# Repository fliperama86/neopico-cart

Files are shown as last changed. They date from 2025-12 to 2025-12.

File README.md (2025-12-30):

# neopico-cart

An open-source Neo Geo MVS/AES flash cartridge using SDRAM instead of expensive parallel SRAM, targeting ~$100 BOM vs ~$1500+ for existing solutions.

## Project Goals

- Support largest games (~96-128 MB total ROM)
- Fast load times (~4 seconds for largest games)
- Cost-effective design using SDRAM with bank interleaving (MiSTer-inspired)
- Open-source hardware and software

## Architecture

```
┌───────────────────────────────────────────────────────────┐
│                      Flash Cart PCB                       │
│                                                           │
│  ┌──────────┐      ┌─────────────┐      ┌─────────────┐  │
│  │ SD Card  │─SPI─▶│  RP2350B    │      │   128MB     │  │
│  │ (.ngfc)  │      │             │      │   SDRAM     │  │
│  └──────────┘      │ • SD/FAT32  │      └──────┬──────┘  │
│                    │ • Menu UI   │             │         │
│                    │ • Config    │         16-bit        │
│                    └──────┬──────┘             │         │
│                           │                    │         │
│                       PIO/QSPI                 │         │
│                      (20-30 MB/s)              │         │
│                           │                    │         │
│                           ▼                    ▼         │
│              ┌────────────────────────────────────────┐  │
│              │          FPGA (ECP5 or Gowin)          │  │
│              │  • SDRAM controller (120MHz)           │  │
│              │  • 4-bank interleaving                 │  │
│              │  • Neo Geo bus interface               │  │
│              │  • Menu video generation               │  │
│              └───────────────────┬────────────────────┘  │
│                                  │                       │
│                           Level Shifters                 │
│                                  │                       │
└──────────────────────────────────┼───────────────────────┘
                                   │ 5V Bus
                                   ▼
                         ┌───────────────────┐
                         │   Neo Geo MVS/AES │
                         │   Cartridge Slot  │
                         └───────────────────┘
```

### Why Two Chips?

**RP2350 (~$1.50)** handles "software" tasks that are easy in C but painful in HDL:
- SD card FAT32 filesystem parsing
- Menu system and user input
- Configuration and save management
- Uses PIO for high-speed FPGA data transfer (20-30 MB/s)

**FPGA** handles timing-critical tasks requiring nanosecond precision:
- SDRAM controller with 4-bank interleaving
- Neo Geo bus interface (<250ns response for C-ROM)
- Real-time data serving during gameplay

Microcontrollers cannot serve real-time bus data due to timing constraints. Only FPGA + fast memory can meet these requirements. MiSTer proves SDRAM works with proper data reorganization and bank interleaving.

### Boot Sequence

1. RP2350 boots, initializes FPGA (bitstream from flash)
2. RP2350 reads SD card, displays menu via FPGA video
3. User selects game
4. RP2350 streams .ngfc file to FPGA via PIO (~4 sec for largest games)
5. FPGA writes to SDRAM as data arrives
6. FPGA switches to "play" mode, serves all bus requests
7. RP2350 monitors for menu button combo

## Bill of Materials Estimate

| Component | Part | Est. Cost |
|---|---|---|
| FPGA | Gowin GW2A-18 or Lattice ECP5-25 | $20 |
| SDRAM | AS4C64M16D3 (128MB) | $10 |
| MCU | RP2350B | $2 |
| Flash | W25Q128 (16MB for menu/loader) | $2 |
| Level Shifters | TXB0108 or similar (×4) | $6 |
| SD Card Slot | micro-SD | $1 |
| Voltage Regulators | 3.3V, 1.2V | $2 |
| PCB | 4-layer, Neo Geo form factor | $15 |
| Passives & Connectors | | $10 |
| **Total** | | **~$70-80** |

With 30% margin for revisions: **~$100**

## Current Status

### Phase 1: Research & Tooling ✅ Complete

- [x] Analyze existing solutions (BackBit, MiSTer, NeoSD)
- [x] Document timing requirements
- [x] Extract MiSTer transformation algorithms
- [x] Create ROM converter tool
- [x] Define NGFC file format
- [x] Cost analysis

### Phase 2: FPGA Development (Next)

- [ ] Set up FPGA toolchain (Gowin or Lattice)
- [ ] Implement SDRAM controller with bank interleaving
- [ ] Benchmark SDRAM latency/bandwidth
- [ ] Implement Neo Geo bus sniffer (for timing analysis)

### Phase 3: Hardware Prototyping

- [ ] Design breakout board for FPGA dev kit → Neo Geo
- [ ] Measure real C-ROM timing on actual hardware
- [ ] Validate timing margins

### Phase 4+: Full Implementation, Testing, Release

## Tools

### NGFC Converter

The `ngfc/` directory contains a Python tool for converting standard Neo Geo ROM sets to the NGFC format, optimized for SDRAM burst access.

```bash
# Convert a MAME ROM set
./ngfc/ngfc_converter.py convert mslug.zip mslug.ngfc

# Verify an NGFC file
./ngfc/ngfc_converter.py verify mslug.ngfc
```

See [ngfc/README.md](ngfc/README.md) for full documentation.

## Documentation

- [Feasibility Study](docs/neogeo-flashcart-research.md) - Comprehensive technical analysis
- [NGFC Converter](ngfc/README.md) - ROM conversion tool documentation

## References

- [NeoGeo Development Wiki](https://wiki.neogeodev.org/)
- [MiSTer NeoGeo Core](https://github.com/MiSTer-devel/NeoGeo_MiSTer)
- [BackBit Platinum MVS](https://store.backbit.io/product/backbit-platinum-mvs/)

## License

See [LICENSE](LICENSE) for details.

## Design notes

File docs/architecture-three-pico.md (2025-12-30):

# NeoPico-Cart Architecture: Triple RP2350 Design

## Overview

This document describes the "Triple Pico" architecture for the NeoPico-Cart — a Neo Geo MVS/AES flash cartridge using three RP2350 microcontrollers instead of FPGAs.

**Design Philosophy:**
- PSRAM data buses connect **directly** to Neo Geo (not through Picos)
- Picos handle **address translation only** (like BackBit's FPGA approach)
- Each Pico dedicated to specific timing domains
- Uses .ngfc pre-transformed ROM format

---

## Architecture Diagram

```
┌─────────────────────────────────────────────────────────────────────────┐
│                           PROG Board (Top)                              │
│                                                                         │
│  ┌─────────────────────────────────────────────────────────────────┐   │
│  │                      PICO A (Master)                            │   │
│  │  ┌──────────────┐  ┌──────────────┐  ┌──────────────────────┐  │   │
│  │  │ SD Card      │  │ Menu/UI     │  │ Loading Coordinator  │  │   │
│  │  │ Interface    │  │ (Core 0)    │  │ (Core 1)             │  │   │
│  │  └──────────────┘  └──────────────┘  └──────────────────────┘  │   │
│  │  ┌──────────────────────────┐  ┌──────────────────────────┐    │   │
│  │  │ P-ROM Address Control    │  │ V-ROM Address Control    │    │   │
│  │  │ (PIO 0)                  │  │ (PIO 1)                  │    │   │
│  │  └────────────┬─────────────┘  └────────────┬─────────────┘    │   │
│  └───────────────┼─────────────────────────────┼──────────────────┘   │
│                  │                             │                       │
│         ┌────────▼────────┐           ┌───────▼────────┐              │
│         │ P-ROM PSRAM     │           │ V-ROM PSRAM    │              │
│         │ (16MB)          │           │ (32MB)         │              │
│         └────────┬────────┘           └───────┬────────┘              │
│                  │ D0-D15                     │ SDRAD/SDPAD           │
│                  │ (direct)                   │ (direct)              │
├──────────────────┼─────────────────────────────┼──────────────────────┤
│                  │         FFC Link            │                      │
│                  │      (directly to PSRAM connections)               │
├──────────────────┼────────────────────────────┼───────────────────────┤
│                           CHA Board (Bottom)                          │
│                                                                        │
│  ┌─────────────────────────────┐    ┌─────────────────────────────┐   │
│  │      PICO B (C-ROM)         │    │    PICO C (S/M-ROM)         │   │
│  │  ┌───────────────────────┐  │    │  ┌───────────────────────┐  │   │
│  │  │ C-ROM Address Control │  │    │  │ S-ROM Address Control │  │   │
│  │  │ (PIO 0 + PIO 1)       │  │    │  │ (PIO 0)               │  │   │
│  │  │ PCK1B Handler         │  │    │  │ PCK2B Handler         │  │   │
│  │  └───────────┬───────────┘  │    │  └───────────┬───────────┘  │   │
│  │  ┌───────────┴───────────┐  │    │  ┌───────────────────────┐  │   │
│  │  │ P-Bus Address Capture │  │    │  │ M-ROM Address Control │  │   │
│  │  │ (74HC573 Latches)     │  │    │  │ (PIO 1)               │  │   │
│  │  └───────────────────────┘  │    │  └───────────┬───────────┘  │   │
│  └──────────────┬──────────────┘    └──────────────┼──────────────┘   │
│                 │                                   │                  │
│    ┌────────────▼────────────┐        ┌────────────▼────────────┐     │
│    │ C-ROM PSRAM Array       │        │ S-ROM      │ M-ROM      │     │
│    │ (8× 8MB = 64MB)         │        │ PSRAM      │ PSRAM      │     │
│    └────────────┬────────────┘        │ (1MB)      │ (1MB)      │     │
│                 │ CR0-CR31            └─────┬──────┴─────┬──────┘     │
│                 │ (direct)                  │ FIXD0-7    │ SDD0-7     │
│                 │                           │ (direct)   │ (direct)   │
├─────────────────┼───────────────────────────┼────────────┼────────────┤
│                 │                           │            │            │
│                 ▼                           ▼            ▼            │
│  ┌─────────────────────────────────────────────────────────────────┐ │
│  │                      NEO GEO MAIN BOARD                         │ │
│  │   68000 CPU    LSPC    NEO-B1    NEO-ZMC2    YM2610    Z80     │ │
│  └─────────────────────────────────────────────────────────────────┘ │
└─────────────────────────────────────────────────────────────────────────┘
```

---

## Pico Assignments

### Pico A: Master Controller (PROG Board)

**Primary Responsibilities:**
- SD card interface and file system
- Menu system and user interface
- Game loading coordination
- P-ROM bus address control
- V-ROM bus address control

**Secondary Responsibilities:**
- Stream .ngfc data to Pico B/C during loading
- System coordination and status

| Resource | Allocation |
|---|---|
| Core 0 | Menu system, SD card, UI |
| Core 1 | Loading coordinator, P-ROM PIO management |
| PIO 0 | P-ROM address generation |
| PIO 1 | V-ROM address generation |
| PIO 2 | Inter-Pico communication |

### Pico B: C-ROM Controller (CHA Board)

**Primary Responsibilities:**
- C-ROM bus address control (most complex timing path)
- PCK1B signal handling
- P-bus address capture
- 8× PSRAM chip select management

**Timing Requirements:**
- <250ns from PCK1B edge to data valid
- Target: PSRAM address valid within ~20ns of PCK1B edge for fast access
- At 300MHz overclock: ~6 PIO cycles for address translation

| Resource | Allocation |
|---|---|
| Core 0 | Address translation, bank management |
| Core 1 | Cache/prefetch management (if needed) |
| PIO 0 | P-bus address capture |
| PIO 1 | PSRAM address output |
| PIO 2 | PCK1B edge detection, timing control |

### Pico C: S/M-ROM Controller (CHA Board)

**Primary Responsibilities:**
- S-ROM bus address control (fix layer)
- M-ROM bus address control (Z80 program)
- PCK2B signal handling

**Timing Requirements:**
- S-ROM: <200ns (relaxed compared to C-ROM)
- M-ROM: Relaxed (Z80 @ 4MHz)

| Resource | Allocation |
|---|---|
| Core 0 | S-ROM address management |
| Core 1 | M-ROM address management |
| PIO 0 | S-ROM address generation, PCK2B handling |
| PIO 1 | M-ROM address generation |
| PIO 2 | Inter-Pico communication |

---

## Pin Allocations

### Pico A: Master (PROG Board)

| Function | Signal | Pins | Direction |
|---|---|---|---|
| **P-ROM PSRAM Address** | PA0-PA19 | 20 | Output |
| **P-ROM PSRAM CS** | /PCS | 1 | Output |
| **P-ROM Control** | /ROMOE, R/W, AS | 3 | Input |
| **P-ROM Banking** | SLOTCS, SYSTEMB | 2 | Input |
| **V-ROM PSRAM Address** | VA0-VA19 | (shared with PA) | Output |
| **V-ROM PSRAM CS** | /VCS0, /VCS1 | 2 | Output |
| **V-ROM Control** | /SDRD0, /SDRD1 | 2 | Input |
| **V-ROM Mux** | /SDPOE, SDRMPX | 2 | Input |
| **SD Card SPI** | CS, CLK, MOSI, MISO | 4 | Mixed |
| **FFC Link** | TX, RX, CLK, SYNC | 4 | Mixed |
| **Status LED** | LED | 1 | Output |
| **Reserved** | - | 5 | - |
| **Total** | | **~42** | |

### Pico B: C-ROM (CHA Board)

| Function | Signal | Pins | Direction |
|---|---|---|---|
| **P-Bus Low** | P0-P15 | 16 | Input |
| **P-Bus High** | P16-P23 | 8 | Input |
| **CA4** | CA4 | 1 | Input |
| **C-ROM PSRAM Address** | CA0-CA21 | 22 | Output |
| **C-ROM PSRAM CS** | /CCS0-/CCS7 | 8 | Output |
| **Control Signals** | PCK1B, EVEN, H, LOAD | 4 | Input |
| **Clock Reference** | 12M | 1 | Input |
| **FFC Link** | TX, RX, CLK, SYNC | 4 | Mixed |
| **Total** | | **~48** | |

**Note:** Pico B is at GPIO limit. May use 74HC573 latches to reduce P-bus input pins.

### Pico C: S/M-ROM (CHA Board)

| Function | Signal | Pins | Direction |
|---|---|---|---|
| **S-ROM Address In** | (from P-bus via latch) | 12 | Input |
| **S-ROM PSRAM Address** | SA0-SA16 | 17 | Output |
| **S-ROM PSRAM CS** | /SCS | 1 | Output |
| **S-ROM Control** | PCK2B, 2H1 | 2 | Input |
| **M-ROM Address In** | SDA0-SDA15 | 16 | Input |
| **M-ROM PSRAM Address** | MA0-MA16 | (shared with SA) | Output |
| **M-ROM PSRAM CS** | /MCS | 1 | Output |
| **M-ROM Control** | /SDMRD, /SDROM | 2 | Input |
| **FFC Link** | TX, RX, CLK, SYNC | 4 | Mixed |
| **Reserved** | - | 6 | - |
| **Total** | | **~41** | |

---

## Memory Configuration

### PSRAM Allocation

| ROM Type | PSRAM Chips | Capacity | Controller |
|---|---|---|---|
| C-ROM | 8× APS6404L-3SQR | 64 MB | Pico B |
| P-ROM | 2× APS6404L-3SQR | 16 MB | Pico A |
| V-ROM | 4× APS6404L-3SQR | 32 MB | Pico A |
| S-ROM | 1× APS6404L-3SQR | 128 KB used | Pico C |
| M-ROM | (shared with S) | 128 KB used | Pico C |
| **Total** | **15 chips** | **~120 MB** | |

### PSRAM Interface

Using QSPI PSRAM (e.g., APS6404L):
- 4-bit data width per chip
- 133 MHz max clock
- ~55ns random access latency

**Alternative:** Parallel PSRAM for lower latency but more pins.

For C-ROM (needs 32-bit output):
- Option 1: 8× QSPI PSRAM, parallel chip selects
- Option 2: 4× Octal PSRAM (8-bit each)
- Option 3: Parallel PSRAM with direct Neo Geo connection

**Recommended:** Parallel PSRAM for C-ROM (timing critical), QSPI for others.

---

## Data Flow

### Game Loading Sequence

```
1. User selects game from menu (Pico A)
2. Pico A reads .ngfc header from SD card
3. Pico A allocates PSRAM regions

4. P-ROM loading:
   └── Pico A streams P-ROM section → local PSRAM

5. V-ROM loading:
   └── Pico A streams V-ROM section → local PSRAM

6. C-ROM loading:
   ├── Pico A reads C-ROM section from SD
   ├── Pico A sends over FFC link to Pico B
   └── Pico B writes to C-ROM PSRAM array

7. S-ROM loading:
   ├── Pico A sends S-ROM section to Pico C
   └── Pico C writes to S-ROM PSRAM

8. M-ROM loading:
   ├── Pico A sends M-ROM section to Pico C
   └── Pico C writes to M-ROM PSRAM

9. All Picos switch to "serve" mode
10. Pico A releases Neo Geo reset (game starts)
```

**Expected load time:** ~10-15 seconds for largest games (comparable to BackBit).

### Runtime Data Flow

```
C-ROM Access (per tile):
┌─────────────┐    ┌─────────────┐    ┌─────────────┐    ┌─────────────┐
│ LSPC puts   │───►│ Pico B      │───►│ PSRAM       │───►│ NEO-ZMC2    │
│ addr on     │    │ translates  │    │ outputs     │    │ serializes  │
│ P-bus       │    │ to PSRAM    │    │ CR0-31      │    │ to pixels   │
│             │    │ address     │    │ (direct)    │    │             │
└─────────────┘    └─────────────┘    └─────────────┘    └─────────────┘
     PCK1B ────────────►│
                   ~20ns            ~55ns              ~10ns
                   └────────────── Total: <100ns ──────────────┘
```

---

## Timing Analysis

### C-ROM Critical Path

| Stage | Time | Notes |
|---|---|---|
| PCK1B edge detection | ~3ns | PIO input sync |
| Address capture | ~10ns | From latches or direct |
| Address translation | ~20ns | PIO + bank lookup |
| PSRAM chip select | ~5ns | GPIO output |
| PSRAM access | ~55ns | PSRAM datasheet |
| Data valid on bus | - | Direct connection |
| **Total** | **~93ns** | |

**Available time:** PCK1B period = 666ns, but data needed within <250ns (8 mclk window = ~333ns).

**Margin:** ~157ns — comfortable.

### P-ROM Path

| Stage | Time | Notes |
|---|---|---|
| Address valid | - | From 68000 |
| Address decode | ~30ns | PIO |
| PSRAM access | ~55ns | |
| Data valid | - | Direct |
| **Total** | **~85ns** | |

**Available time:** 150ns minimum (P-ROM spec).

**Margin:** ~65ns — acceptable.

---

## Bill of Materials (Estimated)

| Component | Quantity | Unit Cost | Total |
|---|---|---|---|
| RP2350B (QFN-60) | 3 | $1.50 | $4.50 |
| PSRAM APS6404L-3SQR | 15 | $3.00 | $45.00 |
| Level shifter TXB0108 | 12 | $1.50 | $18.00 |
| 74HC573 Latch | 4 | $0.50 | $2.00 |
| FFC connector (60-pin) | 2 | $1.00 | $2.00 |
| SD card slot | 1 | $1.00 | $1.00 |
| Crystal 12MHz | 3 | $0.30 | $0.90 |
| Voltage regulator 3.3V | 2 | $0.50 | $1.00 |
| Capacitors, resistors | ~50 | $0.02 | $1.00 |
| PCB (2-layer, 2 boards) | 1 set | $15.00 | $15.00 |
| Cartridge shell | 1 | $10.00 | $10.00 |
| **Total BOM** | | | **~$100** |

---

## Advantages

1. **No FPGA required** — All RP2350, single toolchain (C/PIO ASM)
2. **Proven architecture** — Based on BackBit's PSRAM-direct approach
3. **Cost effective** — ~$100 BOM vs $100-200 for BackBit
4. **Flexible** — Easy firmware updates via SD card
5. **Hackable** — Open source, well-documented
6. **.ngfc format** — No runtime data transformation

## Challenges

1. **Pin count tight on Pico B** — May need external latches
2. **PIO timing critical** — C-ROM path needs careful optimization
3. **Inter-Pico bandwidth** — Loading speed limited by FFC link
4. **PSRAM sourcing** — Need reliable supplier for 15 chips
5. **PCB complexity** — Two boards, many traces

## Risks & Mitigations

| Risk | Mitigation |
|---|---|
| PIO too slow for C-ROM | Add 74HC573 latches for address capture |
| PSRAM latency too high | Use parallel PSRAM instead of QSPI |
| Six-slot MVS timing | Optimize PIO, add pipelining |
| Inter-Pico bottleneck | Use parallel FFC, increase clock |

---

## Development Phases

### Phase 1: Bus Sniffer
- Build logic analyzer to capture real Neo Geo timing
- Verify assumptions about PCK1B, address setup times
- Test on various MVS boards (1-slot, 4-slot, 6-slot)

### Phase 2: Single Bus Prototype
- Implement P-ROM only on single Pico
- Validate PSRAM timing
- Test with simple homebrew ROM

### Phase 3: C-ROM Prototype
- Add Pico B for C-ROM
- Most timing-critical validation
- Test sprite rendering

### Phase 4: Full Integration
- Add Pico C for S/M-ROM
- Complete game loading
- Full compatibility testing

### Phase 5: PCB Design
- Design PROG and CHA boards
- Manufacture prototypes
- Case design

---

## References

- `docs/neogeo-mvs-cartridge-reference.md` — Hardware pinout and timing
- `docs/neopico-cart-rp2350-feasibility.md` — RP2350 feasibility analysis
- `docs/neogeo-flashcart-research.md` — BackBit/MiSTer research
- `docs/transcript.txt` — Evie's BackBit presentation
- `ngfc/README.md` — .ngfc format specification

---

*Document version: 1.0*
*Created: December 2024*
*Architecture: Triple RP2350 ("Three Pico")*

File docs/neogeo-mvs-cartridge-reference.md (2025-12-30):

# Neo Geo MVS Cartridge Hardware Reference

A comprehensive technical reference for the Neo Geo MVS cartridge interface, covering pinouts, buses, timing, and signal specifications.

**Sources:** [NeoGeo Development Wiki](https://wiki.neogeodev.org/), [Jamma Nation X](http://www.jamma-nation-x.com/jammax/mvspinout.html), various schematics and community documentation.

---

## Table of Contents

1. [Signal Naming Convention](#signal-naming-convention)
2. [Physical Specifications](#physical-specifications)
3. [Board Structure](#board-structure)
4. [System Clocks](#system-clocks)
5. [ROM Types Overview](#rom-types-overview)
6. [P-ROM Bus (Program)](#p-rom-bus-program)
7. [C-ROM Bus (Sprites)](#c-rom-bus-sprites)
8. [S-ROM Bus (Fix Layer)](#s-rom-bus-fix-layer)
9. [M-ROM Bus (Z80)](#m-rom-bus-z80)
10. [V-ROM Bus (Audio)](#v-rom-bus-audio)
11. [Banking and Memory Mapping](#banking-and-memory-mapping)
12. [Display Timing](#display-timing)
13. [Sprite Rendering Pipeline](#sprite-rendering-pipeline)
13. [Cartridge Pinout](#cartridge-pinout)
14. [Key Chips Reference](#key-chips-reference)
15. [Voltage and Electrical](#voltage-and-electrical)

---

## Signal Naming Convention

Neo Geo signal names follow a consistent pattern: **PREFIX + NUMBER/SUFFIX**

### Prefix = Subsystem

| Prefix | Meaning | Subsystem |
| --- | --- | --- |
| **D** | Data | 68000 CPU data bus |
| **A** | Address | 68000 CPU address bus |
| **P** | P-bus | Internal graphics multiplexed bus |
| **CR** | C-ROM | Sprite graphics data |
| **FIXD** | Fix Data | Fix layer (S-ROM) data |
| **SD** | Sound | Z80/Audio subsystem |
| **SDA**  | Sound Data Address | Z80 address bus |
| **SDD**  | Sound Data Data | Z80 data bus |
| **SDRA** | Sound ADPCM-A | ADPCM channel A address/data |
| **SDPA** | Sound ADPCM-B | ADPCM channel B address/data |

### Suffix = Function or Bit Number

| Suffix  | Meaning | Example |
| --- | --- | --- |
| **0-N** | Bit number | D0-D15 = 16-bit data bus |
| **OE**  | Output Enable | /ROMOE |
| **RD**  | Read strobe | /SDRD0 |
| **WR**  | Write strobe | /PORTWE |
| **CS**  | Chip Select | SLOTCS |
| **B** | Active low or inverted | PCK1B |
| **MRD** | Memory Read | /SDMRD |
| **MPX** | Multiplex control | SDRMPX |
| **L/U** | Lower/Upper byte | /ROMOEL, /ROMOEU |

### Signal Groups

**68000 CPU:**

```
D0-D15      Data bus (16 bits)
A1-A19      Address bus (A0 implied by byte strobes)
/ROMOE      ROM Output Enable
/ROMOEL     ROM Output Enable Lower byte
/ROMOEU     ROM Output Enable Upper byte
R/W         Read/Write direction
AS          Address Strobe
```

**P-Bus (Graphics):**

```
P0-P23      24-bit multiplexed bus (tile numbers, palette, attributes)
```

**C-ROM (Sprites):**

```
CR0-CR31    32-bit sprite data
            CR0-CR15  = odd ROMs (C1, C3, C5...) bitplanes 0,1
            CR16-CR31 = even ROMs (C2, C4, C6...) bitplanes 2,3
CA4         Extra C-ROM address bit
PCK1B       Pixel Clock 1 Bar - latches C-ROM address from P-bus
EVEN        Pixel pair swap control
H           Horizontal flip
LOAD        Serializer load signal
```

**S-ROM (Fix Layer):**

```
FIXD0-FIXD7   8-bit fix layer data
PCK2B         Pixel Clock 2 Bar - latches S-ROM address
2H1           S-ROM address bit 3
```

**Z80 / Sound:**

```
SDA0-SDA15    Z80 Address bus (16 bits)
SDD0-SDD7     Z80 Data bus (8 bits)
/SDMRD        Sound Memory Read
/SDROM        Sound ROM chip select
```

**ADPCM Audio:**

```
SDRA0-SDRA23    ADPCM-A ROM address (low bits multiplexed, high bits direct)
SDRAD0-SDRAD7   ADPCM-A ROM data
/SDRD0          ADPCM-A Read strobe

SDPA8-SDPA11    ADPCM-B ROM address (high bits only, low bits multiplexed)
SDPAD0-SDPAD7   ADPCM-B ROM data
/SDRD1          ADPCM-B Read strobe
```

**Clocks:**

```
24M       Master clock (24 MHz)
12M       CPU/video clock (24÷2 = 12 MHz)
8M        Audio clock (24÷3 = 8 MHz)
6M        Pixel output clock (24÷4 = 6 MHz)
4M        Z80 clock (24÷6 = 4 MHz)
```

### Quick Reference

```
D = 68000 Data          A = 68000 Address
P = Graphics P-bus      CR = C-ROM (sprites)
FIXD = S-ROM (fix)      SD = Sound/Z80

SDA = Z80 Address       SDD = Z80 Data
SDRA = ADPCM-A Addr     SDRAD = ADPCM-A Data
SDPA = ADPCM-B Addr     SDPAD = ADPCM-B Data

PCK1B = C-ROM clock     PCK2B = S-ROM clock
/xxxOE = Output Enable  /xxxRD = Read strobe
B suffix = active low   L/U suffix = lower/upper byte
```

---

## Physical Specifications

| Parameter | Value |
| --- | --- |
| Pin pitch | 0.1 inch (2.54mm) |
| Board thickness | 1.6mm |
| Pins per board | 120 (60 per side) |
| Total pins per cartridge | 240 |
| Connector type | Card edge |
| Board count | 2 (PROG + CHA) |

---

## Board Structure

The Neo Geo cartridge consists of two separate PCBs stacked inside the cartridge shell. Each board has its own edge connector and plugs into a separate slot on the motherboard (CTRG1 for CHA, CTRG2 for PROG):

### CHA Board (Bottom - CTRG1)

**Purpose:** Character/graphics data

| Contents | Description |
| --- | --- |
| C-ROM | Sprite graphics (16-bit pairs) |
| S-ROM | Fix layer graphics (8-bit) |
| M-ROM | Z80 program code (8-bit) |
| NEO-ZMC2 / PRO-CT0 | C-ROM serializer (on some boards) |

### PROG Board (Top - CTRG2)

**Purpose:** Program code and audio samples

| Contents | Description |
| --- | --- |
| P-ROM | 68000 program code (16-bit) |
| V-ROM | ADPCM audio samples |
| Banking logic | For games > 1MB P-ROM |

### Common Board Types

| PROG Board | CHA Board | Max C-ROM | Notes |
| --- | --- | --- | --- |
| PROG-B | CHA-32 | 4MB | Early small games |
| PROG-B | CHA-42 | 8MB | Common mid-era |
| PROGBK1 | CHA256 | 32MB | Large games |
| PROGBK1 | CHA512Y | 64MB | Maximum capacity  |

**Note:** Later boards (post-1999) may include encryption chips (NEO-CMC, NEO-SMA).

---

## System Clocks

All timing derives from a master crystal oscillator:

| Signal | Frequency | Derivation | Generator | Purpose |
| --- | --- | --- | --- | --- |
| **24M** | 24.000 MHz (MVS) / 24.167829 MHz (AES) | Master clock | Crystal | Reference |
| **12M** | 12 MHz | 24M ÷ 2 | NEO-D0 | 68000 CPU, NEO-ZMC2 |
| **8M** | 8 MHz | 24M ÷ 3 | LSPC2-A2  | YM2610 sound chip |
| **6M** | 6 MHz | 24M ÷ 4 | NEO-D0 | Pixel clock, video output |
| **4M** | 4 MHz | 24M ÷ 6 | LSPC2-A2  | Z80 CPU |
| **3M** | 3 MHz | 24M ÷ 8 | NEO-D0 | NEO-B1 |
| **68KCLK** | 12 MHz | = 12M | NEO-D0 | 68000 clock input |

**1 mclk (master clock cycle) = 41.67 ns**

**1 pixel = 4 mclk = 166.67 ns**

---

## ROM Types Overview

| ROM Type  | Bus Width | Max Capacity (Official) | Largest Known | Timing Requirement | Purpose |
| --- | --- | --- | --- | --- | --- |
| **P-ROM** | 16-bit | 1MB (Direct) / 8MB (Banked) | 8MB (KOF 2003) | 150ns | 68000 program |
| **C-ROM** | 32-bit | 64MB (Direct) / 128MB+ (Banked) | 64MB (Garou/KOF) | <250ns (~8 mclk) | Sprite graphics |
| **S-ROM** | 8-bit | 128KB (Direct) / 512KB (Banked) | 512KB (KOF 2000) | ~200ns (uncertain) | Fix layer graphics |
| **M-ROM** | 8-bit | 128KB (Banked) | 128KB (Standard) | Relaxed | Z80 program |
| **V-ROM** | 8-bit | 32MB (Direct) / 64MB+ (Banked)  | ~48MB (KOF 2003) | A: >2μs, B: 250ns  | ADPCM samples |

**Note on Total Size and Banking:**
The "Giga Power" marketing label refers to cartridges reaching 1024 Megabits (**128MB**) total. While physical pins have limits (e.g., 64MB for C-ROM on a `CHA512Y` board), games used custom mappers (`NEO-CMC`, `NEO-SMA`) to bank data. _Garou: Mark of the Wolves_ is approximately **86MB** (688Mb) total, with 64MB dedicated to C-ROM. Modern flashcarts should target **128MB** total capacity to support all official titles and large homebrew.

---

## P-ROM Bus (Program)

### Overview

The P-ROM contains 68000 machine code. It connects to the main CPU data and address buses.

### Specifications

| Parameter | Value |
| --- | --- |
| Data bus width | 16 bits (D0-D15) |
| Address bus | A1-A19 (directly addressable: 1MB) |
| Minimum speed  | 150ns |
| Access type | Asynchronous with /DTACK |

### Memory Map

| Address Range | Size | Description |
| --- | ---- | --- |
| $000000-$0FFFFF | 1MB  | P-ROM (directly mapped) |
| $200000-$2FFFFF | 1MB  | P-ROM bank window (if banked) |

### Banking

Games larger than 1MB use bank switching:

- Banks are typically 1MB each
- Controlled by writes to specific addresses
- Some games use NEO-SMA for banking + encryption

**Note:** For 2MB P-ROM, mapping is inverted: second 1MB at $000000, first 1MB at $200000.

### Control Signals

| Signal  | Description |
| --- | --- |
| /ROMOE  | P1 ROM output enable |
| /ROMOEL | P ROM lower byte enable |
| /ROMOEU | P ROM upper byte enable |
| /DTACK  | Data acknowledge to CPU |
| R/W | Read/Write direction |
| AS | Address strobe |

---

## C-ROM Bus (Sprites)

### Overview

The C-ROM bus is the most timing-critical. It feeds sprite graphics data to the video pipeline for real-time rendering.

### Specifications

| Parameter | Value |
| --- | --- |
| Data bus width | 32 bits (CR0-CR31) |
| Organization | Paired 16-bit ROMs (odd/even)  |
| Max capacity | 64MB+ (with banking) |
| Timing requirement | <250ns (see timing note below) |
| Tiles per scanline | Max 96 |

### ROM Pairing

C-ROMs are organized in pairs, each containing half the bitplanes:

| ROM | Contains | Bitplanes |
| --- | --- | --- |
| Odd (C1, C3, C5...)  | First half  | 0, 1 |
| Even (C2, C4, C6...) | Second half | 2, 3 |

Both ROMs are read simultaneously, providing 32 bits (4 bytes) per access.

### Address Latching

C-ROM addresses are extracted from the multiplexed P-bus using latch chips:

| Signal | Function |
| --- | --- |
| **PCK1B** | Clock to latch C-ROM address |
| P0-P23 | Multiplexed address from LSPC |
| CA4 | Separate address bit (not on P-bus) |

**PCK1B Timing:**

- Frequency: 1.5 MHz
- Low period: 55ns (address setup)
- High period: 610ns (data valid window)
- **Total period: ~666ns (16 mclk)**

**C-ROM Timing Note:** Two C-ROM reads occur per PCK1B period (16 pixels / 8 pixels per read = 2 reads), giving ~8 mclk (~333ns) per read. The <250ns ROM speed requirement provides adequate margin. The wiki states "anything under 250ns" works reliably.

### Tile Format

Sprites are 16×16 pixels, 4 bits per pixel (16 colors):

```
Tile structure: 128 bytes total
├── 4 quadrants of 8×8 pixels each
├── Each quadrant: 32 bytes
├── Rows stored backwards within quadrant
└── Bitplanes split across ROM pairs
```

### Serialization

The 32-bit parallel data must be serialized to 4-bit pixels:

| Chip | Location | Function |
| --- | --- | --- |
| NEO-ZMC2 | Motherboard (AES) or CHA board | Serializes C-ROM data |
| PRO-CT0  | CHA board variant | Alternative serializer  |
| NEO-CMC  | CHA board (late games) | Serializer + encryption |

**NEO-ZMC2 Timing:**

- Clock: 12 MHz
- Latches data on rising edge of 12M
- Outputs next pixel on falling edge

---

## S-ROM Bus (Fix Layer)

### Overview

The S-ROM contains the "fix" layer - static text/UI graphics that overlay sprites.

### Specifications

| Parameter | Value |
| --- | --- |
| Data bus width | 8 bits (FIXD0-FIXD7) |
| Max capacity | 128KB (banked with NEO-CMC)  |
| Timing requirement | ~200ns (5-6 mclk, uncertain) |
| Tile size | 8×8 pixels, 4bpp |

### Tile Format

Fix tiles are 8×8 pixels, 4 bits per pixel:

```
Storage: 32 bytes per tile
├── Pixels coded in pairs as bytes
├── Stored in columns (top to bottom)
├── Pixel order swapped within byte:
│   └── Left pixel: bits 0-3
│   └── Right pixel: bits 4-7
└── Column order: mixed (not linear)
```

### Address Format

```
Address bits: ...nHCLLL
├── n: Tile number
├── H: Half (0=right, 1=left)
├── C: Column within half
└── L: Line number (0-7)
```

### Address Latching

| Signal | Function |
| --- | --- |
| **PCK2B** | Clock to latch S-ROM address |
| 2H1 | Separate address bit (SA3) |

---

## M-ROM Bus (Z80)

### Overview

The M-ROM contains the Z80 sound CPU program code.

### Specifications

| Parameter | Value |
| --- | --- |
| Data bus width | 8 bits (SDD0-SDD7) |
| Address bus | 16 bits (SDA0-SDA15) |
| Max capacity | 128KB (64KB directly + banking) |
| Timing requirement | Relaxed (Z80 @ 4MHz) |

### Banking

For M-ROM > 64KB:

- NEO-ZMC or NEO-ZMC2 handles bank switching
- Lower 32KB: Fixed
- Upper 32KB: Bankable window

### Control Signals

| Signal | Function |
| --- | --- |
| /SDMRD | M-ROM read enable |
| /SDROM | ROM chip select |

---

## V-ROM Bus (Audio)

### Overview

V-ROMs contain ADPCM audio samples for the YM2610 sound chip.

### Specifications

The YM2610 has two ADPCM channels with different timing:

| Channel | Bus Width | Timing Requirement | Typical Size |
| --- | --- | --- | --- |
| ADPCM-A | 8-bit | >2μs | Variable |
| ADPCM-B | 8-bit | 250ns | Variable |

### Address Buses

**ADPCM-A:**

- SDRAD0-SDRAD7 (multiplexed)
- SDRA8-SDRA9, SDRA20-SDRA23

**ADPCM-B:**

- SDPAD0-SDPAD7 (multiplexed)
- SDPA8-SDPA11

### Control Signals

| Signal | Function |
| --- | --- |
| /SDRD0 | ADPCM-A ROM read  |
| /SDRD1 | ADPCM-B ROM read  |
| /SDPOE | PCM output enable |

---

## Display Timing

### Frame Structure (NTSC)

| Parameter | Value |
| --- | --- |
| Resolution | 320×224 visible  |
| Total pixels | 384×264 |
| Frame rate | ~59.185 Hz |
| Scanline duration | 1536 mclk (64μs) |

### Horizontal Timing (per scanline)

| Phase | Duration (mclk) | Duration (px) | Duration (μs) |
| --- | --- | --- | --- |
| H-Sync | 112 | 28 | 4.67 |
| Back porch | 112 | 28 | 4.67 |
| **Active display** | 1280 | 320 | 53.33 |
| Front porch | 32 | 8 | 1.33 |
| **H-Blank total**  | 256 | 64 | 10.67 |
| **Total** | 1536 | 384 | 64.00 |

### Vertical Timing (NTSC)

| Phase | Scanlines |
| --- | --- |
| V-Sync | 8 |
| Top border | 16 (blanked) |
| **Active display** | 224 |
| Bottom border | 16 (blanked) |
| **Total** | 264 |

### Blanking Signals

| Signal | Function |
| --- | --- |
| CHBL | Horizontal blanking - forces palette 0, color 0 |
| BNKB | Vertical blanking - forces DAC to 0 |

---

## Sprite Rendering Pipeline

### Overview

The LSPC chip renders sprites using a line buffer architecture with pipelined parsing and rendering.

### Line Buffer Architecture

```
4 line buffers (160 pixels each, odd/even interleaved)
├── Buffer pair A: Rendering
└── Buffer pair B: Output to display
(Swapped each scanline)
```

Two pixels are rendered simultaneously via odd/even buffer pairs.

### Pipeline Timing

| Line N-2 | Line N-1 | Line N |
| --- | --- | --- |
| Parse sprites for N | Render sprites for N | Output line N |

### Sprite Parsing (during line N-2)

1. Read Y position of each sprite (up to 381)
2. Check if sprite visible on line N
3. Add visible sprites to active list
4. Stop when: 381 sprites parsed OR 96 sprites in list

### Sprite Limits

| Limit | Value | Notes |
| --- | --- | --- |
| Sprites per scanline | 96 | Hardware limit |
| Sprites per frame | 381 | VRAM constraint allows 448, but parsing limited |
| Sprite priority | 1 = back, higher = front | |

### C-ROM Access Pattern

Per rendered tile line:

1. PCK1B rises → Address latched from P-bus
2. Address decoded to C-ROM
3. 32-bit data read from C-ROM pair
4. NEO-ZMC2 serializes to 2 pixels at a time
5. Pixels written to line buffer

**Timing budget per tile: ~666ns (PCK1B period)**

---

## Cartridge Pinout

### CHA Board (CTRG1) - Bottom Board

**Top Side (Component side facing up):**

| Pin | Signal | Pin | Signal |
| --- | --- | --- | --- |
| 1 | GND | 31  | CR16 |
| 2 | GND | 32  | CR17 |
| 3 | P0 | 33  | CR18 |
| 4 | P1 | 34  | CR19 |
| 5 | P2 | 35  | CR20 |
| 6 | P3 | 36  | CR21 |
| 7 | P4 | 37  | CR22 |
| 8 | P5 | 38  | CR23 |
| 9 | P6 | 39  | CR24 |
| 10  | P7 | 40  | CR25 |
| 11  | P8 | 41  | CR26 |
| 12  | P9 | 42  | CR27 |
| 13  | P10 | 43  | CR28 |
| 14  | P11 | 44  | CR29 |
| 15  | P12 | 45  | CR30 |
| 16  | P13 | 46  | CR31 |
| 17  | P14 | 47  | FIXD0  |
| 18  | P15 | 48  | FIXD1  |
| 19  | P16 | 49  | FIXD2  |
| 20  | P17 | 50  | FIXD3  |
| 21  | P18 | 51  | FIXD4  |
| 22  | P19 | 52  | FIXD5  |
| 23  | P20 | 53  | FIXD6  |
| 24  | P21 | 54  | FIXD7  |
| 25  | P22 | 55  | SDD4 |
| 26  | P23 | 56  | SDD5 |
| 27  | PCK1B  | 57  | SDD6 |
| 28  | PCK2B  | 58  | SDD7 |
| 29  | VCC | 59  | VCC |
| 30  | VCC | 60  | VCC |

**Bottom Side:**

| Pin | Signal | Pin | Signal |
| --- | --- | --- | --- |
| 1 | GND | 31  | CR0 |
| 2 | GND | 32  | CR1 |
| 3 | CA4 | 33  | CR2 |
| 4 | 2H1 | 34  | CR3 |
| 5 | 24M | 35  | CR4 |
| 6 | 12M | 36  | CR5 |
| 7 | 8M | 37  | CR6 |
| 8 | EVEN | 38  | CR7 |
| 9 | LOAD | 39  | CR8 |
| 10  | H | 40  | CR9 |
| 11  | RESET  | 41  | CR10 |
| 12  | SDA0 | 42  | CR11 |
| 13  | SDA1 | 43  | CR12 |
| 14  | SDA2 | 44  | CR13 |
| 15  | SDA3 | 45  | CR14 |
| 16  | SDA4 | 46  | CR15 |
| 17  | SDA5 | 47  | SDA8 |
| 18  | SDA6 | 48  | SDA9 |
| 19  | SDA7 | 49  | SDA10  |
| 20  | SDA12  | 50  | SDA11  |
| 21  | SDA13  | 51  | SDRD0  |
| 22  | SDA14  | 52  | SDRD1  |
| 23  | SDA15  | 53  | SDROM  |
| 24  | SDMRD  | 54  | SDDO |
| 25  | SDD0 | 55  | GND |
| 26  | SDD1 | 56  | GND |
| 27  | SDD2 | 57  | GND |
| 28  | SDD3 | 58  | GND |
| 29  | VCC | 59  | VCC |
| 30  | VCC | 60  | VCC |

### PROG Board (CTRG2) - Top Board

**Top Side:**

| Pin | Signal | Pin | Signal |
| --- | --- | --- | --- |
| 1 | GND | 31  | D8 |
| 2 | GND | 32  | D9 |
| 3 | D0 | 33  | D10 |
| 4 | D1 | 34  | D11 |
| 5 | D2 | 35  | D12 |
| 6 | D3 | 36  | D13 |
| 7 | D4 | 37  | D14 |
| 8 | D5 | 38  | D15 |
| 9 | D6 | 39  | SDRA8  |
| 10  | D7 | 40  | SDRA9  |
| 11  | A1 | 41  | SDRA20 |
| 12  | A2 | 42  | SDRA21 |
| 13  | A3 | 43  | SDRA22 |
| 14  | A4 | 44  | SDRA23 |
| 15  | A5 | 45  | SDRAD0 |
| 16  | A6 | 46  | SDRAD1 |
| 17  | A7 | 47  | SDRAD2 |
| 18  | A8 | 48  | SDRAD3 |
| 19  | A9 | 49  | SDRAD4 |
| 20  | A10 | 50  | SDRAD5 |
| 21  | A11 | 51  | SDRAD6 |
| 22  | A12 | 52  | SDRAD7 |
| 23  | A13 | 53  | SDPA8  |
| 24  | A14 | 54  | SDPA9  |
| 25  | A15 | 55  | SDPA10 |
| 26  | A16 | 56  | SDPA11 |
| 27  | A17 | 57  | GND |
| 28  | A18 | 58  | GND |
| 29  | VCC | 59  | VCC |
| 30  | VCC | 60  | VCC |

**Bottom Side:**

| Pin | Signal  | Pin | Signal |
| --- | --- | --- | --- |
| 1 | GND | 31  | R/W |
| 2 | GND | 32  | AS |
| 3 | A19 | 33  | /ROMOE |
| 4 | (NC) | 34  | 4MB |
| 5 | SYSTEMB | 35  | /ROMOEU |
| 6 | SLOTCS  | 36  | /ROMOEL |
| 7 | /RESET  | 37  | /PORTOEL  |
| 8 | ROMWAIT | 38  | /PORTOEU  |
| 9 | PWAIT0  | 39  | /PORTADRS |
| 10  | PWAIT1  | 40  | /PORTWE |
| 11  | PDTACK  | 41  | VPA |
| 12  | SDD0 | 42  | SDPAD0 |
| 13  | SDD1 | 43  | SDPAD1 |
| 14  | SDD2 | 44  | SDPAD2 |
| 15  | SDD3 | 45  | SDPAD3 |
| 16  | SDD4 | 46  | SDPAD4 |
| 17  | SDD5 | 47  | SDPAD5 |
| 18  | SDD6 | 48  | SDPAD6 |
| 19  | SDD7 | 49  | SDPAD7 |
| 20  | /SDPOE0 | 50  | /SDPOE1 |
| 21  | /SDROE  | 51  | /SDRMPX |
| 22  | /SDRA00 | 52  | /SDRMPX |
| 23  | /SDRA01 | 53  | SDRA00 |
| 24  | SDRA02  | 54  | SDRA01 |
| 25  | SDRA03  | 55  | SDRA02 |
| 26  | SDRA04  | 56  | SDRA03 |
| 27  | SDRA05  | 57  | SDRA04 |
| 28  | SDRA06  | 58  | SDRA05 |
| 29  | VCC | 59  | VCC |
| 30  | VCC | 60  | VCC |

**Note:** Original schematics had /ROMOE and 4MB swapped. Corrected pinout shown above.

---

## Key Chips Reference

### LSPC (Line Sprite Controller)

| Function | Description |
| --- | --- |
| Sprite parsing | Evaluates which sprites visible per line |
| P-bus control | Multiplexes tile/palette data |
| Timing generation | PCK1B, PCK2B, blanking signals |
| Line buffer control | CK1-4, WE signals |

### NEO-B1

| Function | Description |
| --- | --- |
| Line buffers | Handles sprite rendering into internal line buffers |
| Palette interface | Outputs addresses to external 4KB palette RAM |
| Color lookup | Converts tile pixels to RGB via DAC |
| Fix layer rendering | Real-time overlay on sprite buffer output |

**Note:** The 4KB palette RAM consists of external SRAM chips; NEO-B1 interfaces with but does not contain this memory.

### NEO-ZMC2 / PRO-CT0

| Function | Description |
| --- | --- |
| C-ROM serialization | 32-bit parallel → 4-bit serial |
| Horizontal flip | Reverses pixel order |
| EVEN swap | Swaps pixel pairs |
| M-ROM banking | Address generation for Z80 |

### NEO-D0

| Function | Description |
| --- | --- |
| Clock generation | Divides 24M to 12M (÷2), 6M (÷4), 3M (÷8) |
| Watchdog | System reset on hang (via CHBL counter) |
| Z80 control | Memory and port control, YM2610 interface |
| Memory card | Bank selection control |

**Note:** The calendar/RTC is handled by a separate D4990 chip, not NEO-D0. LSPC2-A2 generates 8M (÷3) and 4M (÷6) clocks.

### YM2610

| Function | Description |
| --- | --- |
| Sound generation | FM synthesis + ADPCM playback |
| V-ROM interface  | Dual ADPCM channels (A + B) |
| SSG | 3-channel square wave |

---

## Voltage and Electrical

### Power Rails

| Rail | Voltage | Purpose |
| ---- | --- | --- |
| VCC  | +5V | Logic and ROMs |
| GND  | 0V | Ground reference |

### Signal Levels

| Parameter | Value |
| --- | --- |
| Logic family | 5V TTL/CMOS |
| VOH (output high) | >2.4V |
| VOL (output low)  | <0.4V |
| VIH (input high)  | >2.0V |
| VIL (input low) | <0.8V |

### Level Shifting Considerations

Modern components (3.3V FPGA, MCU, PSRAM) require level shifting:

| Approach | Latency | Notes |
| --- | --- | --- |
| Auto-sensing bidirectional | 8-15ns  | Avoid for timing-critical signals |
| Direction-specified | 3-8ns | Preferred (e.g., TI TXB series) |
| Series resistor + clamp | <1ns | Works for some inputs |

**Critical:** Level shifter latency directly impacts timing budget.

---

## References

- [NeoGeo Development Wiki](https://wiki.neogeodev.org/)
- [Jamma Nation X MVS Pinout](http://www.jamma-nation-x.com/jammax/mvspinout.html)
- [MiSTer Neo Geo Core](https://github.com/MiSTer-devel/NeoGeo_MiSTer)
- Original SNK schematics (various sources)

---

_Document version: 1.5_
_Created: December 2025_
_Last updated: December 2025 - Added dedicated Banking and Memory Mapping section_

### Changelog

- **v1.5**: Added a dedicated "Banking and Memory Mapping" section to explain logic locations (Cartridge vs. Console) and mechanisms for all subsystems.
- **v1.4**: Corrected C-ROM vs. Total Cartridge size for _Garou_ (64MB C-ROM, 86MB Total), updated V-ROM maximum to _KOF 2003_ (~48MB), and clarified "Giga Power" 128MB limit.
- **v1.3**: Updated ROM Types Overview with official maximums for "Giga Power" era games (e.g., 8MB P-ROM, 86MB C-ROM), clarified banking logic and the meaning of the "+" size indicators.
- **v1.2**: Removed incorrect ribbon cable claim (boards use separate edge connectors CTRG1/CTRG2), clarified C-ROM timing window (~8 mclk per read, not 7 mclk).
- **v1.1**: Corrected clock generation attribution (NEO-D0 vs LSPC2-A2), clarified NEO-D0 functions (calendar is D4990, not NEO-D0), updated NEO-B1 description (palette RAM is external), noted S-ROM timing uncertainty.

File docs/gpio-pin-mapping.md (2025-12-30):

# GPIO Pin Mapping

MVS Cart Edge → RP2350B GPIO assignments for neopico-cart.

## Pico A: P/V-ROM Controller

### From MVS PROG Connector (Input)
| GPIO | MVS Signal | MVS Pin | Notes |
|---|---|---|---|
| 0-15 | D0-D15 | Top 3-10, 31-38 | P-ROM data (bidir) |
| 16-34 | A1-A19 | Top 11-27, Bot 3 | P-ROM address |
| 35 | /ROMOE | Bot 33 | Output enable |
| 36 | R/W | Bot 31 | Read/Write |
| 37 | SLOTCS | Bot 6 | Slot select |

### To PSRAM (Output)
| GPIO | Signal | Notes |
|---|---|---|
| 38-41 | QSPI_D0-D3 | PSRAM data |
| 42 | QSPI_CLK | PSRAM clock |
| 43-44 | /CS_P, /CS_V | PSRAM chip selects |

---

## Pico B: C-ROM Controller

### From MVS CHA Connector (Input)
| GPIO | MVS Signal | MVS Pin | Notes |
|---|---|---|---|
| 0-7 | CA3-CA10 | Top 21-28 | C-ROM tile address |
| 8 | PCK1B | Top 7 | Pixel clock |
| 9 | EVEN/ODD | Top 6 | Line select |

### To MVS CHA Connector (Output)
| GPIO | MVS Signal | MVS Pin | Notes |
|---|---|---|---|
| 10-41 | CR0-CR31 | Top 1-4 (×8 banks) | C-ROM 32-bit data out |

### To PSRAM (Output)
| GPIO | Signal | Notes |
|---|---|---|
| 42-47 | /CS0-CS5 | PSRAM array selects |

---

## Pico C: S/M-ROM Controller

### From MVS CHA Connector (Input)
| GPIO | MVS Signal | MVS Pin | Notes |
|---|---|---|---|
| 0-11 | Fix addr | via latch | S-ROM address |
| 12 | PCK2B | Top 53 | Fix layer clock |
| 13 | /SFIX | Top 57 | S-ROM enable |

### To MVS CHA Connector (Output)
| GPIO | MVS Signal | MVS Pin | Notes |
|---|---|---|---|
| 14-21 | FD0-FD7 | Top 37-44 | S-ROM data |
| 22-29 | SDA0-SDA7 | Bot 12-19 | M-ROM data (Z80 sound) |

---

*Pin assignments are preliminary. GPIO numbers will change based on PIO requirements and PCB routing.*

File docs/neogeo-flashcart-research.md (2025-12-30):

# Neo Geo Flash Cart Feasibility Study

## Project Goal

Evaluate the feasibility of building a Neo Geo MVS/AES flash cartridge using modern microcontrollers (RP2350) and/or FPGAs, with acceptable load times (~12 seconds) and no persistence requirement during gameplay.

---

## Neo Geo Hardware Overview

### System Architecture

The Neo Geo uses a multi-bus architecture with separate ROM buses for different subsystems:

| Bus | Purpose | Size (Largest Games) | Timing Criticality |
|-----|---|---|---|
| **C-ROM** | Sprite graphics | ~64 MB (Garou/KOF) | **Critical** (real-time rendering) |
| **S-ROM** | Fix layer graphics | ~512 KB | Medium |
| **M-ROM** | Z80 sound program | ~128 KB | Low |
| **V-ROM** | ADPCM audio samples | ~48 MB (KOF 2003) | Medium (buffered) |
| **P-ROM** | 68000 program code | ~8 MB (KOF 2003) | High (CPU wait states) |
| **Total** | **All ROMs** | **~128 MB (Max Official)** | **Target Capacity** |
new_string_2:
**Total ROM for largest games**: ~128 MB (Garou: Mark of the Wolves is ~86 MB total)

### Critical Timing Constraints

From the [NeoGeo Development Wiki](https://wiki.neogeodev.org/):

- **Master clock**: 24 MHz (1 mclk = 41.67 ns)
- **C-ROM rendering**: 16 mclk per sprite tile line = 666.7 ns total
- **C-ROM reads per tile**: 2 reads per 16-pixel line = 333.3 ns per access
- **PCK1B latch frequency**: 1.5 MHz (55 ns low, 610 ns high)
- **C-ROM access requirement**: <250 ns (~8 mclk window, per NeoGeo Dev Wiki)
- **NEO-ZMC2 serializer**: 12 MHz clock (internal timing, not the C-ROM requirement)
- **Minimum VRAM access**: ~45 ns (1.5 mclk = 62.5 ns slots)

**Key insight**: The C-ROM bus requires data within **<250ns** of address latch. This is comfortable for PSRAM (55ns access) as BackBit demonstrates.

---

## Existing Solutions Analysis

### BackBit Platinum MVS

**Source**: Evie Salomon's VCF SoCal 2025 presentation

The BackBit Platinum is a commercial Neo Geo flash cart that provides key architectural insights.

#### Hardware Architecture

**Two-board design**:
1. **PROG Board**: Handles P-ROM (68000) and memory card buses
2. **CHA Board**: Handles Z80, C-ROM, S-ROM buses

**Memory Configuration**:

| ROM Type | Memory Technology | Details |
|---|---|---|
| All ROMs | **PSRAM** | Pseudo-Static RAM stores entire loaded game |

From Evie's VCF SoCal 2025 presentation:
> - *"PSRAM (Pseudo-Static Random Access Memory) stores loaded game"*
> - *"The FPGA plays traffic cop to serve PSRAM to the NEO GEO, support banking and emulating the link"*
> - *"The data lines of the RAM chips are connected to the CPU, but not to the FPGA"*

**Key insight**: PSRAM serves data **directly** to Neo Geo buses — the FPGA only handles address translation and banking, NOT data. No FPGA BRAM caching required!

**Why PSRAM works** (from Evie):
> *"The nice thing about the PS RAM is that on the outside, it operates just like a traditional static RAM chip from way back when. So, it can serve data pretty quick without having to send it a lot of series of commands."*

This avoids high-speed PCB design (>25-50 MHz) required for SDRAM.

**FPGA Configuration**:
- 2× Lattice iCE40 FPGAs (largest flat-pack version to avoid BGA assembly costs)
- Functions: Address decode, bank switching, link emulation
- **FPGA is NOT in the data path** — saves pins and latency
- FPGA controls PSRAM address lines; PSRAM data lines connect directly to Neo Geo

**Memory Configuration**:
- 8× PSRAM chips for C-ROM (64 MB total, ~8 MB each)
- Additional PSRAM for P/V/S/M-ROM

**Microcontroller (STM32)**:
- Role: SD card access, menu system, loading ROM data into PSRAM
- **NOT involved in real-time bus serving**
- Pipelines data over 80-bit bus to FPGAs during loading
- Total load time: ~12 seconds for largest games

**Key challenges mentioned**:
- **Metastability**: Unsettled FPGA inputs can cascade unknown states through gate chains
- **Six-slot MVS machines**: Bus multiplexing across 6 slots adds significant latency
- **Bidirectional address bus**: Input from Neo Geo, output to PSRAM requires careful timing
- **Level shifter latency**: Must use direction-specified shifters (not auto-sensing) to minimize delay

#### Key Insights from BackBit

1. **PSRAM is fast enough for ALL ROMs including C-ROM** — no caching needed, direct bus connection
2. **FPGA handles addressing only** — data path is PSRAM → Neo Geo directly (saves FPGA pins)
3. **Microcontrollers cannot serve real-time bus data** — only for loading/menu
4. **PSRAM behaves like classic SRAM** — simple interface, no command sequences like SDRAM
5. **Avoids high-speed PCB design** — staying under 25-50 MHz simplifies layout
6. **12-second load time is acceptable** — users tolerate this for the capability
7. **Latency optimization is critical** — metastability, level shifters, bus direction all add up

#### BackBit Cost Implications

Estimated BOM for the PSRAM + FPGA approach:
- ~10× PSRAM chips (8 for C-ROM + others): ~$40-80
- 2× iCE40 FPGAs (flat-pack, not BGA): ~$10-20
- Level shifters (TI, direction-specified): ~$20-40
- STM32 MCU: ~$5-10
- Passives, connectors, PCBs: ~$30-50
- **Total estimated BOM: ~$105-200**

This is significantly cheaper than fast parallel SRAM would be, making the $400 pre-order / $500 retail pricing profitable.

---

### MiSTer FPGA Neo Geo Core

**Source**: Furrtek's NeoGeo_MiSTer repository, DEV_NOTES.md, community discussions

The MiSTer Neo Geo core solves the same fundamental problem (feeding C-ROM data fast enough) but with a completely different approach.

#### Architecture Differences

| Aspect | BackBit (Real Hardware) | MiSTer (FPGA Emulation) |
|---|---|---|
| Memory Type | 10ns Parallel SRAM | **SDR SDRAM @ 120-144 MHz** |
| Memory Cost (128MB) | ~$1500+ | **~$30-50 (single chip!)** |
| How it works | Direct bus connection | Pre-arranged data, burst reads |
| Timing constraint | Must respond to real Neo Geo | **Is** the Neo Geo, can adjust timing |

#### How MiSTer Makes SDRAM Work

From DEV_NOTES.md:

> *"The SDRAM extension board stores the 68k program, sprites and fix graphics. It currently runs at **120MHz** but may be pushed up to **144MHz** if needed."*

> *"The sprite data is **re-organized during loading** so that the bitplane data can be read in **4-word bursts** and used as-is."*

**Key techniques**:

1. **Data reorganization at load time**
   - ARM CPU shuffles ROM data into SDRAM-optimal layout
   - Sprite tiles arranged for sequential burst access
   - Fix graphics reordered to minimize random access

2. **Burst mode reads**
   - Read 4 words (64 bits) per burst instead of single words
   - First word: ~20 ns, subsequent words: ~8 ns each
   - 4-word burst = ~44 ns for 64 bits

3. **Bank interleaving**
   - SDRAM has 4 independent banks
   - While one bank completes access, start another
   - Achieves ~4× effective bandwidth

4. **Smart scheduling**
   - FPGA knows which subsystem needs data next
   - Schedules accesses to maximize parallelism
   - Uses auto-precharge to close rows automatically

#### SDRAM Bank Interleaving Explained

Standard SDRAM random access timing:
```
Single read cycle: ACT → wait(tRCD) → RD → wait(CL) → DATA
Total: ~60-90 ns per word at 100 MHz
```

With 4-bank interleaving:
```
Clock:  1    2    3    4    5    6    7    8    9    10
Bank 0: ACT  ---  RD   ---  ---  DATA ---  ---  ---  ACT...
Bank 1: ---  ACT  ---  RD   ---  ---  DATA ---  ---  ---
Bank 2: ---  ---  ACT  ---  RD   ---  ---  DATA ---  ---
Bank 3: ---  ---  ---  ACT  ---  RD   ---  ---  DATA ---
DQ Bus:                          D0   D1   D2   D3
```

**Result**: After pipeline fill, one word every ~2.5 cycles instead of ~9 cycles = **~4× throughput**

#### MiSTer Bandwidth Analysis

At 120 MHz with interleaving and 4-word bursts:
- ~50 ns per 64-bit tile line
- Theoretical max: ~160 MB/s
- Usable (after refresh, other accesses): ~80-100 MB/s

Neo Geo sprite requirements:
- Worst case: 96 tiles × 262 lines × 60 fps = ~1.5 million tile reads/sec
- Each tile = 64 bits = ~12 MB/s peak for sprites

**Conclusion**: SDRAM bandwidth is ~8× what's needed for sprites, with plenty left for CPU and audio.

#### Why MiSTer's Approach Works

The critical difference: **MiSTer IS the Neo Geo**.

- The FPGA implements the LSPC, NEO-ZMC2, and all other chips
- It can reorganize its internal pipeline to accommodate SDRAM latency
- It can prefetch data before it's needed
- It doesn't have to meet external timing constraints

A flash cart doesn't have this luxury — it must interface with **real** Neo Geo hardware that expects data on specific bus cycles.

---

## MiSTer Source Code Analysis

### Overview

The MiSTer Neo Geo core is the best-documented working example of SDRAM-based sprite delivery. By analyzing the actual source code, we can extract the exact algorithms needed for a potential flash cart design.

**Key files:**
- `neogeo_loader.cpp` — ROM loading and data transformation (Linux side)
- `sdram.sv` — SDRAM controller (FPGA side)  
- `sdram_mux.sv` — Memory access multiplexer
- `neogeo.sv` — Top-level core with memory addressing

### Sprite (C-ROM) Data Transformation

From `neogeo_loader.cpp`, the critical transformation function:

```cpp
// Fix layer (S-ROM) transformation for SDRAM burst access
// Comment from source: "To take advantage of the SDRAM burst read feature, 
// the data can be loaded so that all 8 pixels of a tile line can be read sequentially"

for (uint32_t i = 0; i < size; i++) 
    buf_out[i] = buf_in[(i & ~0x1F) | ((i >> 2) & 7) | ((i & 1) << 3) | (((i & 2) << 3) ^ 0x10)];
```

**Breaking down the bit manipulation:**
```
Input byte index:    i = AAAAA_BBBBB (where AAAAA is high bits, BBBBB is low 5 bits)
                         bits [31:5] | bits [4:0]

Output index formula:
  (i & ~0x1F)           → Keep high bits unchanged (tile boundary)
  | ((i >> 2) & 7)      → Bits 4:2 → position 2:0 (shift for burst alignment)
  | ((i & 1) << 3)      → Bit 0 → position 3 (odd/even byte swap)
  | (((i & 2) << 3) ^ 0x10) → Bit 1 → position 4, XOR with 0x10

Result: Data is reordered within each 32-byte tile so SDRAM bursts return 
        pixels in the order the video hardware needs them.
```

### C-ROM Byte Swapping

Also from `neogeo_loader.cpp`:

```cpp
// C-ROM loading includes byte swapping for SDRAM word alignment
for (uint32_t i = 0; i < size; i++) 
    buf[i] = (buf[i] & 0xFF0000FF) | ((buf[i] & 0xFF00) << 8) | ((buf[i] & 0xFF0000) >> 8);
```

This swaps the middle two bytes of each 32-bit word:
```
Input:  [B3][B2][B1][B0]
Output: [B3][B1][B2][B0]
```

Why? The original C-ROM pairs (C1+C2, C3+C4) store bitplanes split across chips. This swap interleaves them for sequential SDRAM access.

### SDRAM Address Mapping

From `DEV_NOTES.md` — how C-ROM addresses are mapped to SDRAM:

```
C-ROM index bits: x1BBBBBS
  B: 512KB bank number (5 bits = 32 banks)
  S: word shift (used to interleave odd/even ROMs)

SDRAM address = 0x0800000 + 0b1_BBBBB000_00000000_000000S0 + ioctl_addr
```

This places C-ROM data at offset 0x0800000 (8 MB) in SDRAM, with each 512KB bank aligned to SDRAM row boundaries for efficient burst access.

### Sprite Data Flow in Hardware

From `DEV_NOTES.md`:

```
1. PCK1B rises → triggers SDRAM read
2. SDRAM controller performs 4-word burst read
3. 64 bits (complete 16-pixel tile line) arrives
4. CA4 signal selects which 8-pixel group feeds NEO-ZMC2
5. CLK_12M latches data when LOAD is high
```

**Timing budget:**
- PCK1B period: ~666 ns
- SDRAM burst read (4 words): ~44 ns at 120 MHz
- Data muxing and output: ~10 ns
- **Margin: ~600 ns** — plenty of time!

### Fix Layer (S-ROM) Transformation

The fix layer uses a different transformation optimized for its access pattern:

```
Original storage (column-major, as in ROM):
  column 2 (lines 0~7), column 3 (lines 0~7), column 0 (lines 0~7), column 1 (lines 0~7)

SDRAM storage (line-major, for burst access):
  line 0 (columns 0~3), line 1 (columns 0~3), ...

Byte remapping:
  Original: 10 18 00 08 11 19 01 09 12 1A 02 0A 13 1B 03 0B ...
  SDRAM:    10-18 00-08 11-19 01-09 12-1A 02-0A 13-1B 03-0B ...
```

### SDRAM Controller Parameters

From the source code comments:

```
SDRAM clock: 120 MHz (may push to 144 MHz)
Configuration: SDR SDRAM, CL2 or CL3
Row activation (tRCD): 2-3 clocks
CAS latency: 2-3 clocks
Burst length: 4 words
Bank interleaving: Yes (4 banks)
Auto-precharge: Used for most reads
```

### Data Interleaving Pattern

The C-ROM data is interleaved as follows:

```
Original C-ROM pairs:
  C1: Bitplanes 0, 1 for tiles 0-N
  C2: Bitplanes 2, 3 for tiles 0-N

After transformation for SDRAM:
  Byte order: C2 C2 C1 C1 C2 C2 C1 C1 ...
  Bitplane order per line: 0 1 2 3 0 1 2 3 ...

Complete 16-pixel line = 4 bitplanes × 16 pixels = 64 bits = four 16-bit SDRAM words
```

This means ONE burst read returns an entire tile line ready for the NEO-ZMC2.

### Key Implementation Insights

1. **Pre-transformation is essential**: The ARM CPU on MiSTer spends significant time reorganizing ROM data during loading. This is a one-time cost that enables efficient runtime access.

2. **Burst alignment matters**: Data must be aligned so that a single SDRAM burst returns exactly what the hardware needs — no wasted bandwidth on unused bytes.

3. **Bank interleaving is the key**: Without interleaving, SDRAM would be far too slow. With it, effective latency drops from ~70 ns to ~20 ns.

4. **Prefetch window exists**: PCK1B gives ~666 ns to fetch 64 bits. Even with SDRAM latency, there's plenty of margin.

5. **Real-time transformation impossible**: The bit manipulation required cannot be done in real-time at 24 MHz. Must be pre-computed.

---

## Memory Technology Analysis

### Parallel SRAM

| Speed | Part Example | Density | Chips for 80MB | Cost/Chip | Total Cost |
|---|---|---|---|---|---|
| 10 ns | AS6C4008 | 4 Mbit | 160 | ~$8-12 | ~$1280-1920 |
| 45 ns | AS6C8008 | 8 Mbit | 80 | ~$8.60 | ~$688 |
| 55 ns | AS6C8008 | 8 Mbit | 80 | ~$5.60 | ~$448 |

**Verdict**: Only 10 ns SRAM meets C-ROM timing directly. Slower SRAM might work with interleaving.

### PSRAM (Pseudo-Static RAM)

**Octal PSRAM** (APMemory APS12808L):
- Access time: 70-150 ns random access
- Cost: 128 Mbit (16 MB) ~$4.60 each
- 80 MB = ~$28 total (6 chips)
- **Verdict**: **Proven to work for ALL ROMs including C-ROM** (BackBit)

**QPI PSRAM**:
- Similar timing to Octal
- BackBit uses PSRAM for ALL ROM types including C-ROM

**Key insight from BackBit**: PSRAM works for C-ROM **without caching**. From Evie:
> *"The nice thing about the PS RAM is that on the outside, it operates just like a traditional static RAM chip from way back when. So, it can serve data pretty quick without having to send it a lot of series of commands."*

The architecture:
1. PSRAM data lines connect **directly** to Neo Geo buses
2. FPGA handles address translation/banking only (not in data path)
3. No high-speed PCB design needed (stays under 25-50 MHz)

This is simpler than SDRAM approaches and avoids FPGA BRAM caching complexity.

### HyperRAM

- Command/Address phase: 3 clock cycles (18 ns at 166 MHz)
- Initial access latency: 3-6 clock cycles
- **Total first-byte latency: ~54 ns minimum** at 166 MHz
- Burst throughput: 333-400 MB/s
- Cost: 64 Mbit (8 MB) ~$8 each, 80 MB = ~$80

**Verdict**: Latency too high for random C-ROM access, but excellent for sequential/burst workloads.

### SDR SDRAM

- Row activation (tRCD): ~15-20 ns
- CAS latency (CL2/CL3): 2-3 clocks = ~20-30 ns at 100 MHz
- Row precharge (tRP): ~15-20 ns
- **Single random access: ~60-90 ns**
- **With bank interleaving: ~15-20 ns effective**
- Cost: 512 Mbit (64 MB) ~$5-10 each

**Verdict**: Too slow for direct random access, but **viable with bank interleaving and prefetching** (as proven by MiSTer).

### RLDRAM3 (Reduced Latency DRAM)

- Designed for random access: 8-16 banks
- Access time: ~10 ns random access
- Cost: 576 Mbit-1 Gbit ~$30-50 each
- **Verdict**: Best DRAM for random access, but expensive and hard to source

---

## RP2350 Role Analysis

### What RP2350 Can Do

- SD card interface and file management
- Menu system and UI
- Loading ROM data into RAM (replacing STM32)
- Control signals to FPGA
- Dual QSPI support for faster loading
- PIO state machines for custom protocols

### What RP2350 Cannot Do

**Real-time bus serving** — confirmed impossible by Evie Salomon:

> *"The timing would be way too tight to do that with any microcontroller"*

The RP2350 runs at 150 MHz (6.67 ns/cycle). A C-ROM access requires:
- Detect address on bus
- Decode address
- Fetch data from memory
- Place data on bus

With the actual <250ns requirement (not the previously assumed ~40-60ns), PSRAM-based solutions become viable. The RP2350's PIO can handle address translation while PSRAM serves data directly to the Neo Geo bus, similar to BackBit's architecture.

### RP2350 Advantages Over STM32

- Lower cost
- More GPIO for control
- Dual-core for parallel tasks
- PIO for fast protocol handling
- Better availability

---

## Alternative Design Strategies

### Strategy 1: Interleaved Slower SRAM

Use 2+ banks of 55 ns SRAM with alternating access:
- While Bank A settling, Bank B delivers data
- Requires address prediction in FPGA
- Neo Geo sprite rendering is somewhat predictable (vertical strips)

**Cost**: ~$448 for 80 MB (vs $1500+ for 10ns)

**Risk**: Requires careful timing validation on real hardware

### Strategy 2: Hybrid Cache + Backing Store

- Small fast cache: 256 KB-1 MB of 10 ns SRAM
- Large backing store: 80 MB PSRAM/HyperRAM
- Cache sprite tiles as accessed

**Cost**: ~$100-150 total

**Risk**: Cache misses during rendering cause visible glitches

### Strategy 3: SDRAM with Prefetch (MiSTer-inspired)

This is the most promising cost-reduction approach:

```
┌─────────────────────────────────────────────────────────┐
│                    FPGA (ECP5/Gowin)                    │
│  ┌───────────────────────────────────────────────────┐  │
│  │           Sprite Prefetch Engine                  │  │
│  │  1. Monitor LSPC sprite evaluation signals        │  │
│  │  2. Predict next ~8 sprite tiles needed           │  │
│  │  3. Prefetch from SDRAM into tile cache           │  │
│  │  4. Serve data from cache on PCK1B                │  │
│  └───────────────────────────────────────────────────┘  │
│                         │                               │
│                         ▼                               │
│  ┌───────────────────────────────────────────────────┐  │
│  │       Tile Line Cache (FPGA BRAM)                 │  │
│  │       ~8-16 tile lines = 512-1024 bytes           │  │
│  │       Access time: 1 FPGA clock (~8 ns)           │  │
│  └───────────────────────────────────────────────────┘  │
│                         │                               │
│                         ▼                               │
│  ┌───────────────────────────────────────────────────┐  │
│  │    Bank-Interleaved SDRAM Controller              │  │
│  │    @ 120-144 MHz, 4-bank interleaving             │  │
│  │    4-word burst reads                             │  │
│  │    ~40-50 ns per tile line (64 bits)              │  │
│  └───────────────────────────────────────────────────┘  │
└─────────────────────────┬───────────────────────────────┘
                          │
                          ▼
             ┌─────────────────────────┐
             │    128 MB SDR SDRAM     │
             │    (AS4C32M16SB)        │
             │    ~$5-10 per chip      │
             └─────────────────────────┘
```

**How prefetch works**:
1. LSPC evaluates sprites during horizontal blanking (~15 μs before rendering)
2. FPGA snoops sprite evaluation to see which tiles are coming
3. Prefetches tile data from SDRAM into BRAM cache
4. When PCK1B fires, serves data from cache in ~10 ns

**Timing budget**:
- 15 μs (15,000 ns) to prefetch ~96 tiles
- 96 tiles × 50 ns = 4,800 ns
- **Plenty of margin!**

**Cost**: ~$45 total (SDRAM + FPGA)

**Risk**: Requires deep understanding of LSPC timing; cache misses cause glitches

### Strategy 4: "Lite" Cart for Smaller Games

Support only games up to 32 MB C-ROM (most pre-1996 titles):
- 32× 8 Mbit 55 ns SRAM = ~$180 for C-ROM
- Covers: Fatal Fury series, Art of Fighting, Samurai Shodown 1-2, Metal Slug 1, etc.

**Cost**: ~$250-300 total BOM

**Risk**: Limited game compatibility

---

## Cost Comparison Summary

| Approach | Memory Cost | FPGA/Logic | Total BOM |
|---|---|---|---|
| BackBit (PSRAM + FPGA cache) | ~$30-60 | ~$20-50 | ~$100-210 |
| 55ns SRAM Interleaved | ~$450 | ~$40 | ~$500 |
| Hybrid Cache | ~$100 | ~$40 | ~$200 |
| SDRAM + Prefetch | ~$10 | ~$50 | ~$100 |
| Lite Cart (32MB) | ~$180 | ~$40 | ~$250 |

**Note**: BackBit's PSRAM approach is comparable in cost to SDRAM + prefetch, validating that expensive fast SRAM is not required.

---

## Critical Unknowns (Updated)

1. ~~**Can slower memory work for C-ROM?**~~ — **ANSWERED: Yes!** BackBit proves PSRAM works with direct connection (no caching!)
2. ~~**Is FPGA caching required?**~~ — **ANSWERED: No!** PSRAM connects directly to Neo Geo data bus; FPGA handles addressing only
3. **Exact PSRAM part numbers used?** — Evie mentions 8 MB chips for C-ROM, but specific parts unknown
4. **Which iCE40 variant?** — "Largest flat-pack" suggests iCE40HX4K or HX8K in TQFP package
5. **Six-slot MVS compatibility** — Evie mentioned this required additional latency optimization
6. **Exact NEO-ZMC2 timing margins?** — No detailed timing diagrams found

---

## NeoPico-Cart Implementation

Based on this research, a concrete architecture has been designed for the NeoPico-Cart project:

**See: `docs/architecture-three-pico.md`**

The "Triple Pico" design uses 3× RP2350 microcontrollers instead of FPGAs:
- PSRAM connects directly to Neo Geo data buses (like BackBit)
- Picos handle address translation only (like BackBit's FPGAs)
- .ngfc format eliminates runtime data transformation
- Estimated BOM: ~$100

---

## Recommended Next Steps

### Phase 1: Research & Planning
1. Study MiSTer Neo Geo source code (SDRAM controller, sprite rendering)
2. Document LSPC sprite evaluation timing from NeoGeo Dev Wiki
3. Analyze feasibility of prefetch prediction

### Phase 2: Prototyping
1. Acquire dev board (Tang Nano 20K, ULX3S, or similar)
2. Implement basic SDRAM controller with bank interleaving
3. Test achievable bandwidth and latency

### Phase 3: Hardware Testing
1. Build simple logic analyzer to capture Neo Geo bus timing
2. Measure actual C-ROM access timing requirements
3. Test interleaved SRAM approach on real hardware

### Phase 4: Integration
1. Design PCB with chosen architecture
2. Implement full flash cart logic
3. Test with variety of games

---

---

## ROM Format Analysis

### TerraOnion NeoSD .neo Format

The NeoSD uses a proprietary `.neo` ROM format created by TerraOnion's NeoBuilder tool.

**Key characteristics:**
- Simple container format with header + concatenated ROM data
- Data is **uncompressed and decrypted**
- ROMs are stored in order: P, S, M, V1, V2, C

**Header structure** (from TerraOnion Wiki):
```
Header contains sizes for each ROM section:
- PSize: Program ROM size (max 1+8 MB)
- SSize: Fix tiles size (max 512 KB)  
- MSize: Z80 program size (max 256 KB)
- V1Size: ADPCM-A samples
- V2Size: ADPCM-B samples (0 if merged with V1)
- CSize: Sprite graphics (max 64 MB officially, larger for hacks)

Data follows header in P, S, M, V1, V2, C order
```

**Important insight**: The .neo format does **NOT** appear to reorganize sprite data for optimized access — it simply concatenates the decrypted ROMs. Any data reorganization for faster access must happen during loading into the flash cart's memory.

### NeoSD Hardware Architecture

From TerraOnion documentation:

- **Processor**: ARM Cortex M4 @ 168 MHz
- **FPGAs**: Two Lattice XP2 FPGAs
- **Memory**: 768 Mbit flash (enough for largest games)
- **NeoSD Pro**: 3840 Mbit total (4× flash slots + 1× SRAM slot)

The NeoSD Pro's RAM slot has "very fast loading times" compared to flash, suggesting they use SRAM for the volatile slot — similar to BackBit's approach.

### MiSTer ROM Data Reorganization

**This is critical**: MiSTer reorganizes ROM data during loading to optimize SDRAM access patterns.

From DEV_NOTES.md:

**Fix layer (S-ROM) reorganization:**
> *"The fix data is re-organized during loading so that pixel pairs are kept adjacent in the SDRAM. This allows to do only one read for 4 pixels."*

Original storage (column-major):
```
column 2 (lines 0~7), column 3 (lines 0~7), column 0 (lines 0~7), column 1 (lines 0~7)
```

Reorganized for SDRAM (line-major):
```
line 0 (columns 0~3), line 1 (columns 0~3)...
```

**Sprite graphics (C-ROM) reorganization:**
> *"The sprite data is re-organized during loading so that the bitplane data can be read in 4-word bursts and used as-is."*

Original C-ROM byte order:
```
C2 C2 C1 C1 C2 C2 C1 C1...
```

Reorganized bitplane order:
```
0 1 2 3 0 1 2 3...
```

**Result**: Complete 16-pixel line = 64 bits = four 16-bit SDRAM words, readable in a single burst.

### Original Neo Geo Sprite Format

From the NeoGeo Development Wiki:

- Sprites are 16×16 pixel tiles, 4 bits per pixel (16 colors)
- Stored as 4× 8×8 pixel blocks
- Each row stored backwards in 4-bit planar organization
- **Bitplanes split across ROM pairs**:
  - Odd C-ROMs (C1, C3, C5, C7): Bitplanes 0 and 1
  - Even C-ROMs (C2, C4, C6, C8): Bitplanes 2 and 3

This split across ROM pairs is why original hardware has **two parallel data buses** for C-ROM — both halves are read simultaneously.

### Implications for Flash Cart Design

**Option A: Store data in original format**
- Requires two separate memory reads per tile line
- Must meet original timing (~333 ns per read)
- Simpler loading, complex real-time access

**Option B: Reorganize data (MiSTer approach)**
- Single burst read for complete tile line
- Relaxed timing requirements (burst-friendly)
- Complex loading, simpler real-time access
- **Enables use of cheaper SDRAM**

**Option C: Hybrid approach**
- Store in optimized format
- Prefetch into small cache
- Serve from cache at full speed

### Custom ROM Format Proposal

For a low-cost flash cart, we could define a custom ROM format optimized for SDRAM burst access.

#### Proposed Format: `.ngfc` (Neo Geo Flash Cart)

```
Header (64 bytes):
  Offset 0x00: Magic number "NGFC" (4 bytes)
  Offset 0x04: Version (2 bytes)
  Offset 0x06: Flags (2 bytes) - encryption, region, etc.
  Offset 0x08: NGH number (4 bytes)
  Offset 0x0C: PSize (4 bytes) - Program ROM size
  Offset 0x10: SSize (4 bytes) - Fix layer size
  Offset 0x14: MSize (4 bytes) - Z80 program size  
  Offset 0x18: VSize (4 bytes) - Combined ADPCM size
  Offset 0x1C: CSize (4 bytes) - Sprite data size (after transformation)
  Offset 0x20: Original CSize (4 bytes) - For verification
  Offset 0x24: CRC32 (4 bytes)
  Offset 0x28: Reserved (24 bytes)

Data sections (in order):
  P-ROM: Original format (CPU timing is relaxed)
  S-ROM: Line-major reorganization (MiSTer algorithm)
  M-ROM: Original format (Z80 timing is relaxed)
  V-ROM: Original format (audio is buffered)
  C-ROM: **SDRAM-optimized format** (see below)
```

#### C-ROM Transformation Algorithm

Based on MiSTer's `neogeo_loader.cpp`:

```c
// Step 1: Interleave C1/C2 ROM pairs
// Input:  Separate C1 (bitplanes 0,1) and C2 (bitplanes 2,3) files
// Output: Interleaved buffer with byte order: C2 C2 C1 C1 C2 C2 C1 C1...

void interleave_crom_pair(uint8_t* c1, uint8_t* c2, uint8_t* out, size_t size) {
    for (size_t i = 0; i < size; i += 4) {
        out[i + 0] = c2[i/2 + 0];  // C2 byte 0
        out[i + 1] = c2[i/2 + 1];  // C2 byte 1
        out[i + 2] = c1[i/2 + 0];  // C1 byte 0
        out[i + 3] = c1[i/2 + 1];  // C1 byte 1
    }
}

// Step 2: Byte swap for SDRAM word alignment
// Swaps middle two bytes of each 32-bit word

void byte_swap_crom(uint32_t* buf, size_t count) {
    for (size_t i = 0; i < count; i++) {
        buf[i] = (buf[i] & 0xFF0000FF) 
               | ((buf[i] & 0x0000FF00) << 8) 
               | ((buf[i] & 0x00FF0000) >> 8);
    }
}

// Step 3: Reorder for SDRAM burst access
// Transforms data within each 32-byte tile so a 4-word burst 
// returns pixels in hardware-expected order

void reorder_for_burst(uint8_t* in, uint8_t* out, size_t size) {
    for (size_t i = 0; i < size; i++) {
        size_t j = (i & ~0x1F)                    // Keep tile boundary (bits 31:5)
                 | ((i >> 2) & 7)                 // Shift bits 4:2 → 2:0
                 | ((i & 1) << 3)                 // Move bit 0 → 3
                 | (((i & 2) << 3) ^ 0x10);       // Move bit 1 → 4, XOR with 0x10
        out[j] = in[i];
    }
}
```

#### S-ROM Transformation Algorithm

```c
// Fix layer: Convert column-major to line-major for burst reads
// Original: column 2, column 3, column 0, column 1 (each 8 lines)
// Output:   line 0 cols 0-3, line 1 cols 0-3, etc.

void transform_srom(uint8_t* in, uint8_t* out, size_t size) {
    // Each tile is 32 bytes (8x8 pixels, 4bpp, 2 bytes per row pair)
    for (size_t tile = 0; tile < size / 32; tile++) {
        uint8_t* src = &in[tile * 32];
        uint8_t* dst = &out[tile * 32];
        
        // Remap byte order within tile
        static const uint8_t remap[32] = {
            0x10, 0x18, 0x00, 0x08, 0x11, 0x19, 0x01, 0x09,
            0x12, 0x1A, 0x02, 0x0A, 0x13, 0x1B, 0x03, 0x0B,
            0x14, 0x1C, 0x04, 0x0C, 0x15, 0x1D, 0x05, 0x0D,
            0x16, 0x1E, 0x06, 0x0E, 0x17, 0x1F, 0x07, 0x0F
        };
        
        for (int i = 0; i < 32; i++) {
            dst[i] = src[remap[i]];
        }
    }
}
```

#### Conversion Tool Pseudocode

```python
def convert_to_ngfc(input_path, output_path):
    # Load standard ROMs (MAME or .neo format)
    p_rom = load_prom(input_path)
    s_rom = load_srom(input_path)
    m_rom = load_mrom(input_path)
    v_rom = load_vrom(input_path)
    c_roms = load_crom_pairs(input_path)  # List of (c1, c2) pairs
    
    # Transform S-ROM for burst access
    s_rom_transformed = transform_srom(s_rom)
    
    # Transform and interleave C-ROM pairs
    c_rom_combined = bytearray()
    for c1, c2 in c_roms:
        interleaved = interleave_crom_pair(c1, c2)
        byte_swapped = byte_swap_crom(interleaved)
        burst_ordered = reorder_for_burst(byte_swapped)
        c_rom_combined.extend(burst_ordered)
    
    # Build header
    header = build_ngfc_header(
        p_size=len(p_rom),
        s_size=len(s_rom_transformed),
        m_size=len(m_rom),
        v_size=len(v_rom),
        c_size=len(c_rom_combined),
        original_c_size=sum(len(c1)+len(c2) for c1,c2 in c_roms)
    )
    
    # Write output file
    with open(output_path, 'wb') as f:
        f.write(header)
        f.write(p_rom)
        f.write(s_rom_transformed)
        f.write(m_rom)
        f.write(v_rom)
        f.write(c_rom_combined)
```

#### Benefits of Pre-Transformed Format

1. **Zero runtime transformation** — Flash cart loader simply streams data to SDRAM
2. **Faster load times** — No CPU cycles spent on bit manipulation
3. **Simpler FPGA logic** — Data arrives ready-to-use
4. **Validated once** — Transformation correctness verified by converter tool

#### Compatibility Notes

- The transformation is **reversible** — original data can be reconstructed
- Games with encryption (CMC, SMA) must be **decrypted first** before transformation
- Largest games (Garou, KOF2002) will produce ~90+ MB transformed files
- SD card must be formatted with cluster size >= 32KB for optimal sequential read

A conversion tool would transform standard .neo or MAME ROM sets into this optimized format during PC-side preparation.

---

## References

### Project Documentation
- `docs/architecture-three-pico.md` — NeoPico-Cart implementation design
- `docs/neogeo-mvs-cartridge-reference.md` — MVS hardware pinout and timing
- `docs/neopico-cart-rp2350-feasibility.md` — RP2350 feasibility study
- `docs/transcript.txt` — VCF SoCal 2025 Talk transcript (Evie Salomon, BackBit)
- `ngfc/README.md` — NGFC format specification

### External Resources
- [NeoGeo Development Wiki](https://wiki.neogeodev.org/)
- [BackBit Store](https://store.backbit.io/product/backbit-platinum-mvs/)
- [MiSTer Neo Geo Core](https://github.com/MiSTer-devel/NeoGeo_MiSTer)
- [Furrtek's DEV_NOTES.md](https://github.com/MiSTer-devel/NeoGeo_MiSTer/blob/master/DEV_NOTES.md)
- [SDRAM Controller Tutorial](https://retroramblings.net/?p=1635)
- [TerraOnion NeoBuilder Guide](https://wiki.terraonion.com/index.php/Neobuilder_Guide)
- [neosdconv tool](https://github.com/city41/neosdconv)
- Alliance Memory SRAM Datasheets (AS6C8008 series)

---

## Document History

- **2024-12-13**: Initial compilation of research findings
- **2024-12-13**: Added ROM format analysis (NeoSD .neo format, MiSTer reorganization, custom format proposal)
- **2024-12-13**: Added detailed MiSTer source code analysis including exact transformation algorithms from `neogeo_loader.cpp`
- **2024-12-23**: **MAJOR CORRECTION**: Updated BackBit architecture based on Evie's VCF SoCal 2025 presentation transcript. Key findings:
  - BackBit uses PSRAM for ALL ROMs including C-ROM (not 10ns parallel SRAM)
  - **No FPGA caching required** — PSRAM connects directly to Neo Geo data bus
  - FPGA handles addressing only, not data path
  - 2× iCE40 FPGAs (flat-pack), 8× PSRAM chips for C-ROM
  - This dramatically simplifies the architecture vs. SDRAM+prefetch approaches
- Based on analysis of BackBit Platinum MVS architecture, MiSTer FPGA Neo Geo core, TerraOnion NeoSD, and original MiSTer source code

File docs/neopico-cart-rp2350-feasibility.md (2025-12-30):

# NeoPico-Cart: RP2350-Based Architecture Feasibility Study

## Executive Summary

This document explores the feasibility of building a Neo Geo flash cartridge using RP2350 microcontrollers instead of (or alongside) an FPGA. The key finding is that a **cache-based architecture** — prefetching tile data from backing memory (PSRAM or SDRAM) into fast internal SRAM during horizontal blanking — makes an RP2350-only solution viable.

**Key enablers:**
1. RP2350's 520KB internal SRAM provides massive cache space (vs MiSTer's ~1KB BRAM)
2. The `.ngfc` format pre-transforms ROM data, eliminating real-time processing
3. PIO state machines offer FPGA-like determinism for bus response
4. PicoGUS project proves RP2040/RP2350 can handle real-time bus interfacing

**Update (Dec 2024):** BackBit's VCF SoCal 2025 presentation revealed they use PSRAM (not fast SRAM) for all ROMs including C-ROM, with direct bus connection. This validates PSRAM as a viable backing store option.

---

## The Core Problem

The Neo Geo's C-ROM (sprite graphics) bus has strict timing requirements:

| Parameter | Value |
|---|---|
| Data valid window | <250ns (~8 mclk window) |
| PCK1B period | ~666ns (16 mclk at 24MHz) |
| C-ROM reads per PCK1B | 2 reads (8 mclk/~333ns each) |
| Worst-case tiles per scanline | ~96 |
| Total C-ROM size (largest games) | ~86MB (Garou: Mark of the Wolves) |

The question: **Can an RP2350 serve data fast enough?**

**Note:** Earlier versions of this document incorrectly stated ~40-60ns. The actual requirement per the NeoGeo Dev Wiki is <250ns, which makes direct PSRAM serving (like BackBit) viable.

---

## The .ngfc Format: Why It Matters

The `.ngfc` (Neo Geo Flash Cart) format pre-transforms ROM data on your PC, which is **critical** for an RP2350-only solution.

### Without Pre-Transformation (Original ROM Format)

```
To serve one 16-pixel tile line at runtime:
1. Read from C1 file (bitplanes 0,1)
2. Read from C2 file (bitplanes 2,3)
3. Interleave bytes: C2 C2 C1 C1 C2 C2 C1 C1...
4. Byte swap: [B3][B2][B1][B0] → [B3][B1][B2][B0]
5. Permute within 32-byte blocks (complex bit manipulation)
6. Output to bus

→ Burns CPU cycles, adds latency, probably impossible at Neo Geo speeds
```

### With .ngfc Pre-Transformation

```
To serve one 16-pixel tile line at runtime:
1. Copy 8 bytes from cache to bus

→ Simple memcpy, PIO-friendly, no math
```

### How It Enables RP2350

| Task | Without .ngfc | With .ngfc |
|---|---|---|
| Prefetch | Complex interleaving | Sequential copy |
| Cache management | Must track bitplane pairs | Simple byte ranges |
| Bus response | Real-time transformation | Direct output |
| CPU overhead | High | Minimal |

The transformation algorithms are complex (see `ngfc/ngfc_converter.py`), but they run **once** on your PC — not 15,000 times per second on the microcontroller.

**See also:** `ngfc/README.md` for format specification and usage.

---

## BackBit's Revelation: PSRAM Works Directly

**Source:** Evie Salomon's VCF SoCal 2025 presentation (transcript in `docs/transcript.txt`)

BackBit's commercial Neo Geo flash cart uses a simpler architecture than expected:

```
BackBit Architecture:
┌─────────────────────────────────────────────────────────┐
│  Neo Geo Bus ←──── PSRAM Data Lines (direct connection) │
│       ↑                                                  │
│       │ Address                                          │
│       ↓                                                  │
│  FPGA (address translation/banking only)                │
│       ↑                                                  │
│       │ Control                                          │
│       ↓                                                  │
│  STM32 (SD card, menu, loading only)                    │
└─────────────────────────────────────────────────────────┘
```

**Key findings:**
- PSRAM serves data **directly** to Neo Geo — no FPGA in data path
- FPGA handles **addressing only** (banking, decoding)
- No BRAM caching or prefetch — PSRAM is fast enough as-is
- 8× PSRAM chips for 64MB C-ROM

**Why this matters for RP2350:**
- Validates PSRAM as backing store (simpler than SDRAM)
- But: FPGA does combinatorial address translation (~nanoseconds)
- RP2350 PIO is sequential (~cycles), so we still need the cache approach
- However, PSRAM + cache may be simpler than SDRAM + cache

---

## Why FPGAs Are Traditionally Used

FPGAs (like those in MiSTer and BackBit) offer:

- Unlimited parallel state machines
- Combinatorial logic (zero-cycle response)
- Proven SDRAM/PSRAM controllers
- Perfect determinism

However, the RP2350's PIO subsystem shares many of these properties:

| Aspect | FPGA | RP2350 PIO |
|---|---|---|
| Parallel state machines | Unlimited | 12 (4 per PIO block × 3 blocks) |
| Determinism | Perfect | Perfect |
| Clock speed | ~100-200MHz typical | Up to 300MHz+ overclocked |
| Pin toggle rate | Every clock edge | Every clock edge |
| Cost | $5-50 | ~$1 |

---

## The MiSTer Approach: Prefetch + Cache

MiSTer's Neo Geo core doesn't serve the bus directly from SDRAM. Instead:

```
┌─────────────────────────────────────────────────────────────┐
│                     FPGA                                    │
│  ┌─────────────────────────────────────────────────────┐   │
│  │            BRAM Tile Cache                          │   │
│  │            ~512-1024 bytes                          │   │
│  │            Access time: ~8ns (1 FPGA clock)         │   │
│  └─────────────────────────────────────────────────────┘   │
│         ▲                              │                    │
│         │ Prefetch during              │ Serve during       │
│         │ H-blank (~15μs)              │ active render      │
│         │                              ▼                    │
│  ┌──────┴──────────────┐    ┌─────────────────────────┐    │
│  │  SDRAM Controller   │    │   Neo Geo Bus Interface │    │
│  │  Bank interleaved   │    │   Directly from BRAM    │    │
│  │  ~40-50ns/access    │    │   ~8ns response         │    │
│  └─────────────────────┘    └─────────────────────────┘    │
└─────────────────────────────────────────────────────────────┘
```

### Timing Budget

```
Timeline for one scanline (~64μs total):
├─────────────────────┼──────────────────────────────────────┤
│  H-Blank (~15μs)    │  Active rendering (~49μs)            │
│                     │                                      │
│  LSPC evaluates     │  PCK1B fires, needs data             │
│  sprites            │  within <250ns                       │
│                     │                                      │
│  Prefetch tiles     │  Served from cache or PSRAM          │
│  from SDRAM→BRAM    │                                      │
└─────────────────────┴──────────────────────────────────────┘

Prefetch math:
- 96 tiles × ~50ns SDRAM = 4,800ns needed
- 15,000ns H-blank available
- Margin: 3× headroom
```

**Key insight**: With <250ns requirement, PSRAM (55ns access) can serve directly. Cache architecture still useful for simplifying logic and handling edge cases.

---

## The RP2350 Advantage: Massive Cache

MiSTer's FPGA has limited BRAM (~1-2KB for tile cache). The RP2350 has **520KB of internal SRAM**.

| Cache size | What it holds | RP2350 feasibility |
|---|---|---|
| 1 scanline | ~6KB (96 tiles × 64 bytes) | Easy — 1.2% of SRAM |
| 10 scanlines | ~60KB | Easy — 12% of SRAM |
| Full frame | ~150KB | Possible — 29% of SRAM |
| All of above + code | ~200KB | Still 300KB+ free |

More cache = more tolerance for SDRAM timing variation.

---

## Proposed RP2350 Architecture

### Two Separate Timing Domains

| Domain | Timing Requirement | What Handles It |
|---|---|---|
| SDRAM access | Relaxed (~15μs window) | PIO + DMA, background |
| Neo Geo bus | <250ns (comfortable with PSRAM) | PIO from internal SRAM or direct PSRAM |

### Single RP2350B Design (If Pins Allow)

```
┌─────────────────────────────────────────────────────────────┐
│                      RP2350B @ 300MHz                       │
│                                                             │
│  ┌─────────────────────────────────────────────────────┐   │
│  │              Internal SRAM (520KB)                  │   │
│  │                                                     │   │
│  │   ┌─────────────┐        ┌─────────────────────┐   │   │
│  │   │ Tile Cache  │        │ Code + Buffers      │   │   │
│  │   │ ~64-128KB   │        │ ~300KB+             │   │   │
│  │   │ Double-buf  │        │                     │   │   │
│  │   └─────────────┘        └─────────────────────┘   │   │
│  └──────────▲──────────────────────────│──────────────┘   │
│             │                          │                   │
│             │ DMA prefetch             │ PIO read          │
│             │ (background)             │ (real-time)       │
│             │                          ▼                   │
│  ┌──────────┴──────────┐    ┌─────────────────────────┐   │
│  │  PIO Block 0        │    │  PIO Block 1 + 2        │   │
│  │  SDRAM Controller   │    │  Neo Geo Bus Interface  │   │
│  │  ~20 pins           │    │  C/P/S/M/V ROM buses    │   │
│  └─────────────────────┘    └─────────────────────────┘   │
│             │                          │                   │
└─────────────┼──────────────────────────┼───────────────────┘
              ▼                          ▼
        ┌──────────┐              ┌──────────────┐
        │  SDRAM   │              │  Neo Geo     │
        │  128MB   │              │  Cartridge   │
        │          │              │  Bus         │
        └──────────┘              └──────────────┘
```

### Dual RP2350B Design (Pin-Constrained)

```
┌─────────────────────────────────────────────────────────────┐
│                 Pico A: "Memory Server"                     │
│  ┌─────────────────────────────────────────────────────┐   │
│  │  PIO: SDRAM Controller                              │   │
│  │  DMA: Burst reads into buffer                       │   │
│  │  Core 0: Prefetch scheduling                        │   │
│  │  Core 1: Inter-Pico communication                   │   │
│  └─────────────────────────────────────────────────────┘   │
└─────────────────────────┬───────────────────────────────────┘
                          │ High-speed parallel link
                          │ (PIO, 16-bit @ 150MHz+)
┌─────────────────────────┴───────────────────────────────────┐
│                 Pico B: "Bus Interface"                     │
│  ┌─────────────────────────────────────────────────────┐   │
│  │  Internal SRAM: Tile cache (double-buffered)        │   │
│  │  PIO 0: C-ROM bus interface                         │   │
│  │  PIO 1+2: P/S/M/V bus interfaces                    │   │
│  │  Core 0: Cache management                           │   │
│  │  Core 1: Real-time coordination                     │   │
│  └─────────────────────────────────────────────────────┘   │
└─────────────────────────────────────────────────────────────┘
```

---

## SDRAM Protocol Overview

SDRAM is organized as banks × rows × columns:

- **Banks** (2-4): Independent sheets, can pipeline accesses
- **Rows** (thousands): Opening a row is slow (~20ns)
- **Columns** (hundreds): Once row is open, column access is fast

### Key Commands

| RAS# | CAS# | WE# | Command |
|---|---|-----|---|
| 0 | 1 | 1 | ACTIVATE (open a row) |
| 1 | 0 | 1 | READ |
| 1 | 0 | 0 | WRITE |
| 0 | 1 | 0 | PRECHARGE (close a row) |
| 0 | 0 | 0 | AUTO REFRESH |

### Typical Read Sequence

```
T0    ACTIVATE     Row address    -         "Open row 1234"
T1    NOP          -              -         Wait (tRCD ~20ns)
T2    NOP          -              -         
T3    READ         Column addr    -         "Read column 56"
T4    NOP          -              -         Wait (CAS latency)
T5    NOP          -              -         
T6    -            -              DATA0     First word arrives
T7    -            -              DATA1     Burst continues
T8    -            -              DATA2     
T9    -            -              DATA3     Burst complete
```

### Why .ngfc Format Helps

Pre-transformed ROM data means burst reads return data in the exact order needed:

- Original C-ROM: Bitplanes split across ROM pairs, complex interleaving
- Transformed: Complete 64-bit tile line in 4 consecutive 16-bit words
- Result: One burst read = one tile line, no CPU transformation needed

---

## Backing Store: PSRAM vs SDRAM

Both memory types can work with the cache-based architecture. Here's the tradeoff:

### PSRAM (Pseudo-Static RAM)

**Pros:**
- Simple SRAM-like interface (no command sequences)
- No refresh management
- Easier PIO implementation
- Proven by BackBit for Neo Geo
- No high-speed PCB design needed (<50 MHz)

**Cons:**
- More expensive per MB (~$5-8 per 64Mbit chip)
- Need ~10 chips for full 128MB capacity
- Lower density than SDRAM

**Typical parts:** APMemory APS6404L (64Mbit QSPI), ESP-PSRAM64H

### SDRAM (Synchronous Dynamic RAM)

**Pros:**
- Cheaper per MB (~$5-10 for 512Mbit chip)
- Single chip for 64-128MB
- Well-documented (MiSTer uses this)
- Higher burst throughput

**Cons:**
- Complex protocol (ACTIVATE, READ, PRECHARGE, REFRESH)
- Needs high-speed PCB design (100-144 MHz)
- More complex PIO implementation
- Refresh cycles steal bandwidth

### Recommendation for RP2350

**Start with PSRAM** because:
1. Simpler PIO code to get working
2. BackBit proves it works for Neo Geo specifically
3. Can always "cost reduce" to SDRAM later (Evie mentioned this in her talk)
4. Focus on proving the cache architecture first

```
Development path:
PSRAM (simple, proven) → Get it working → Optimize → SDRAM (optional cost reduction)
```

---

## Prior Art: PicoGUS

The PicoGUS project proves RP2040 + PIO can handle real-time bus interfacing:

- **Hardware**: RP2040 + 8MB SPI PSRAM
- **Bus**: ISA bus (similar timing constraints to Neo Geo)
- **Approach**: Custom PIO code for bus interface + high-speed PSRAM access
- **Clock**: Runs at 280-400MHz overclocked
- **Result**: Successfully emulates Gravis Ultrasound, Sound Blaster, etc.

Key quote from the creator:
> "I've created PIO code to handle the ISA bus and interface with SPI-based PSRAM at higher speed than I could with the RP2040's built-in SPI peripheral"

### What PicoGUS Demonstrates

1. PIO can react to external bus events in real-time
2. External memory (PSRAM) can be accessed fast enough via PIO
3. Overclocking to 300MHz+ is stable and practical
4. DMA keeps CPU free for other tasks

---

## XMOS lib_sdram Reference

XMOS implements a software-driven parallel SDRAM controller:

- **Interface**: 16-bit SDR SDRAM at up to 62.5MHz
- **Pin count**: Only 20 pins (address/data overlaid)
- **Approach**: Deterministic multi-core execution

If XMOS can do software SDRAM at 62.5MHz, PIO at 150-300MHz should exceed this.

---

## Comparison: Option A vs Option B

### Option A: RP2350B + FPGA

| Component | Role |
|---|---|
| RP2350B | SD card, menu, loads ROM into SDRAM |
| FPGA | SDRAM controller, all bus interfaces |

**Pros**: Proven, FPGA handles all timing-critical paths  
**Cons**: Higher cost, more complexity, two different toolchains

### Option B: Dual RP2350B (No FPGA)

| Component | Role |
|---|---|
| RP2350B #1 | SDRAM controller, prefetch engine |
| RP2350B #2 | All Neo Geo bus interfaces, tile cache |

**Pros**: Lower cost, single toolchain, pushes Pico to its limits  
**Cons**: Unproven for this specific application, needs experimentation

---

## Key Insights

### 1. Cache Architecture Eliminates Timing Concerns

By prefetching into internal SRAM during H-blank, SDRAM access timing becomes irrelevant to bus response timing. Two completely decoupled domains.

### 2. RP2350's 520KB SRAM Is Huge

MiSTer's FPGA has ~1KB BRAM for tile cache. RP2350 has 500× more. This provides massive margin for timing variations and simplifies cache management.

### 3. PIO Is Deterministic Like an FPGA

PIO state machines execute one instruction per clock with zero jitter. For real-time bus response, they're functionally equivalent to FPGA logic.

### 4. The Hard Problem Is Already Solved

MiSTer's Neo Geo core proves the prefetch + cache architecture works. The .ngfc format (pre-transformed ROMs) is already defined. What's left is implementation.

### 5. Prior Art Exists

PicoGUS proves RP2040/RP2350 can handle real-time bus interfacing with external memory. The techniques are transferable.

---

## Recommended Next Steps

### Phase 1: Validate Core Assumptions

1. **Build a PIO SDRAM controller**
   - Target: 62.5-100MHz clock, burst reads working
   - Reference: XMOS lib_sdram architecture
   - Measure: Actual latency per burst read

2. **Test internal SRAM access speed**
   - Benchmark: PIO reading from SRAM → outputting to pins
   - Target: <20ns from trigger to data valid

3. **Prototype Neo Geo bus sniffer**
   - Capture actual PCK1B timing on real hardware
   - Measure address-to-data timing requirements
   - Validate <250ns requirement and measure actual margins

### Phase 2: Proof of Concept

1. **Single-game demo**
   - Load one game's .ngfc data into SDRAM at boot
   - Implement prefetch + cache for C-ROM only
   - P/S/M/V can use simpler (slower) approach initially

2. **Timing validation**
   - Run on real Neo Geo hardware
   - Check for visual glitches (cache misses)
   - Profile cache hit rate

### Phase 3: Full Implementation

1. **Complete bus implementation** (all ROM types)
2. **SD card loading and menu system**
3. **PCB design and integration**

---

## Cost Comparison

| Approach | Key Components | Estimated BOM |
|---|---|---|
| BackBit (PSRAM + FPGA) | ~10× PSRAM + 2× iCE40 + STM32 | ~$100-200 |
| FPGA + SDRAM | ECP5/Gowin + SDRAM + RP2350 | ~$50-100 |
| RP2350 + PSRAM | 1-2× RP2350B + PSRAM | ~$40-70 |
| RP2350 + SDRAM | 1-2× RP2350B + SDRAM | ~$30-50 |

**Note:** BackBit's actual BOM is much lower than previously estimated (was wrongly assumed to use expensive 10ns SRAM). The RP2350 approach is cost-competitive with commercial solutions while being simpler to develop.

---

## Conclusion

A multi-RP2350 Neo Geo flash cartridge appears **feasible** based on:

1. The cache architecture decouples backing store timing from bus response timing
2. RP2350's 520KB SRAM provides ample cache space (500× more than MiSTer's BRAM)
3. PIO offers FPGA-like determinism for bus interfaces
4. PicoGUS demonstrates the approach works for similar applications
5. The `.ngfc` format eliminates real-time data transformation
6. **BackBit proves PSRAM works for Neo Geo** — validates our backing store choice

The main risks:
- Uncharted territory for PIO-based memory controllers
- Pin count constraints require multi-Pico design (3× RP2350)
- Six-slot MVS machines have tighter timing (may need optimization)

But the physics work out, BackBit proves the concept, and the potential cost/simplicity benefits justify experimentation.

## Concrete Implementation

Based on this feasibility analysis, a concrete architecture has been designed:

**See: `docs/architecture-three-pico.md`**

The "Triple Pico" architecture uses:
- **Pico A (Master):** SD card, menu, P-ROM, V-ROM
- **Pico B (C-ROM):** Timing-critical sprite graphics
- **Pico C (S/M-ROM):** Fix layer and Z80 program

This design follows BackBit's approach (PSRAM direct to Neo Geo, controller handles addressing only) but replaces the FPGA with RP2350 PIO.

---

## References

### Project Documentation
- `docs/architecture-three-pico.md` — **Concrete implementation design**
- `docs/neogeo-mvs-cartridge-reference.md` — MVS hardware reference (pinout, timing)
- `docs/neogeo-flashcart-research.md` — Flash cart analysis, BackBit/MiSTer
- `docs/transcript.txt` — Evie Salomon's VCF SoCal 2025 presentation transcript
- `ngfc/README.md` — NGFC format specification and converter tool

### External Resources
- [MiSTer Neo Geo Core](https://github.com/MiSTer-devel/NeoGeo_MiSTer)
- [PicoGUS Project](https://github.com/polpo/picogus)
- [rp2040-psram Library](https://github.com/polpo/rp2040-psram)
- [XMOS lib_sdram](https://github.com/xmos/lib_sdram)
- [NeoGeo Development Wiki](https://wiki.neogeodev.org/)
- [RP2350 Datasheet](https://datasheets.raspberrypi.com/rp2350/rp2350-datasheet.pdf)
- [BackBit Store](https://store.backbit.io/product/backbit-platinum-mvs/)

---

*Document created: December 2024*
*Updated: December 2024 — Added BackBit PSRAM findings, .ngfc integration, PSRAM vs SDRAM comparison*

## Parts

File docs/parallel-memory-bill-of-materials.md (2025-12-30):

# Parallel Memory Bill of Materials (BOM)

This document lists the specific **Parallel (Asynchronous) PSRAM and SRAM** chips required for a Direct Access architecture where the Neo Geo addresses memory directly via level shifters.

## 1. Memory Chip Requirements

These chips are selected for their asynchronous parallel interface, matching the "True Direct" addressing model. All parts are **3.3V** and require level shifting for the 5V Neo Geo bus.

| ROM Bus | Target Size | Recommended Part | Manufacturer | Type  | Interface | Est. Price  |
| :--- | :--- | :--- | :--- | :---- | :--- | :--- |
| **C-ROM** | 64 MB | **IS66WVG32M16** | ISSI | PSRAM | 16-bit Async | $12.00 |
| **P-ROM** | 8 MB | **IS66WVE4M16**  | ISSI | PSRAM | 16-bit Async | $3.50 |
| **V-ROM** | 64 MB | **IS66WVG32M16** | ISSI | PSRAM | 16-bit Async | $12.00 |
| **S-ROM** | 1 MB | **IS62WV10248**  | ISSI | SRAM  | 8-bit Async  | $1.80 |
| **M-ROM** | 1 MB | **IS62WV10248**  | ISSI | SRAM  | 8-bit Async  | $1.80 |
| **TOTAL** | **138 MB**  | | | | | **~$31.10** |

### Chip Notes

- **C-ROM / V-ROM**: The `IS66WVG32M16` is a 512Mb (64MB) G-series Async PSRAM. It is the highest density parallel part available.
- **P-ROM**: The `IS66WVE4M16` (64Mb/8MB) is a standard CellularRAM part used in many retro projects.
- **S/M-ROM**: At 1MB and below, high-speed Asynchronous SRAM (e.g., `IS62` series) is cheaper and faster (55ns) than PSRAM.

---

## 2. Supporting Logic (Level Shifting & Banking)

Because the RP2350 (3.3V) and PSRAM (3.3V) must interface with the Neo Geo (5V) across 80+ bits of data and address, level shifting is the primary supporting cost.

| Component | Purpose | Part Example | Quantity | Est. Cost |
| :--- | :--- | :--- | :--- | :--- |
| **Level Shifters**  | 5V ↔ 3.3V Translation | SN74LVC245 / 74LVC16245 | ~20-25 | $9.00 |
| **Shift Registers** | Bank bit storage (A20+) | 74HC595 | 2-4 | $1.00 |
| **Bus Latches** | Address multiplexing (if needed) | 74HC573 | 4-8 | $2.00 |

---

## 3. Total Estimated BOM Cost

| Category | Cost (USD)  |
| :--- | :--- |
| Memory Chips | ~$31.00 |
| Level Shifters | ~$9.00 |
| Passives & Logic | ~$5.00 |
| PCB (4-layer recommended) | ~$5.00 |
| **Grand Total** | **~$50.00** |

_Prices are based on single-unit retail (Mouser/Digi-Key) as of Dec 2025._

---

## 4. Architectural Implications

- **Zero Data Path Latency**: Unlike Serial/Octal PSRAM, the Pico does not sit in the data path. Data is available at the speed of the silicon (~70ns).
- **Pin Count**: A parallel 64MB chip uses 41+ pins. This architecture requires external hardware (latches/shift registers) or multiple microcontrollers to manage the "Mapper" (Banking) role.
- **Bus Sniffing**: The RP2350's primary role during gameplay is watching the bus for bank-switch writes and updating the external address registers (Shift Registers).

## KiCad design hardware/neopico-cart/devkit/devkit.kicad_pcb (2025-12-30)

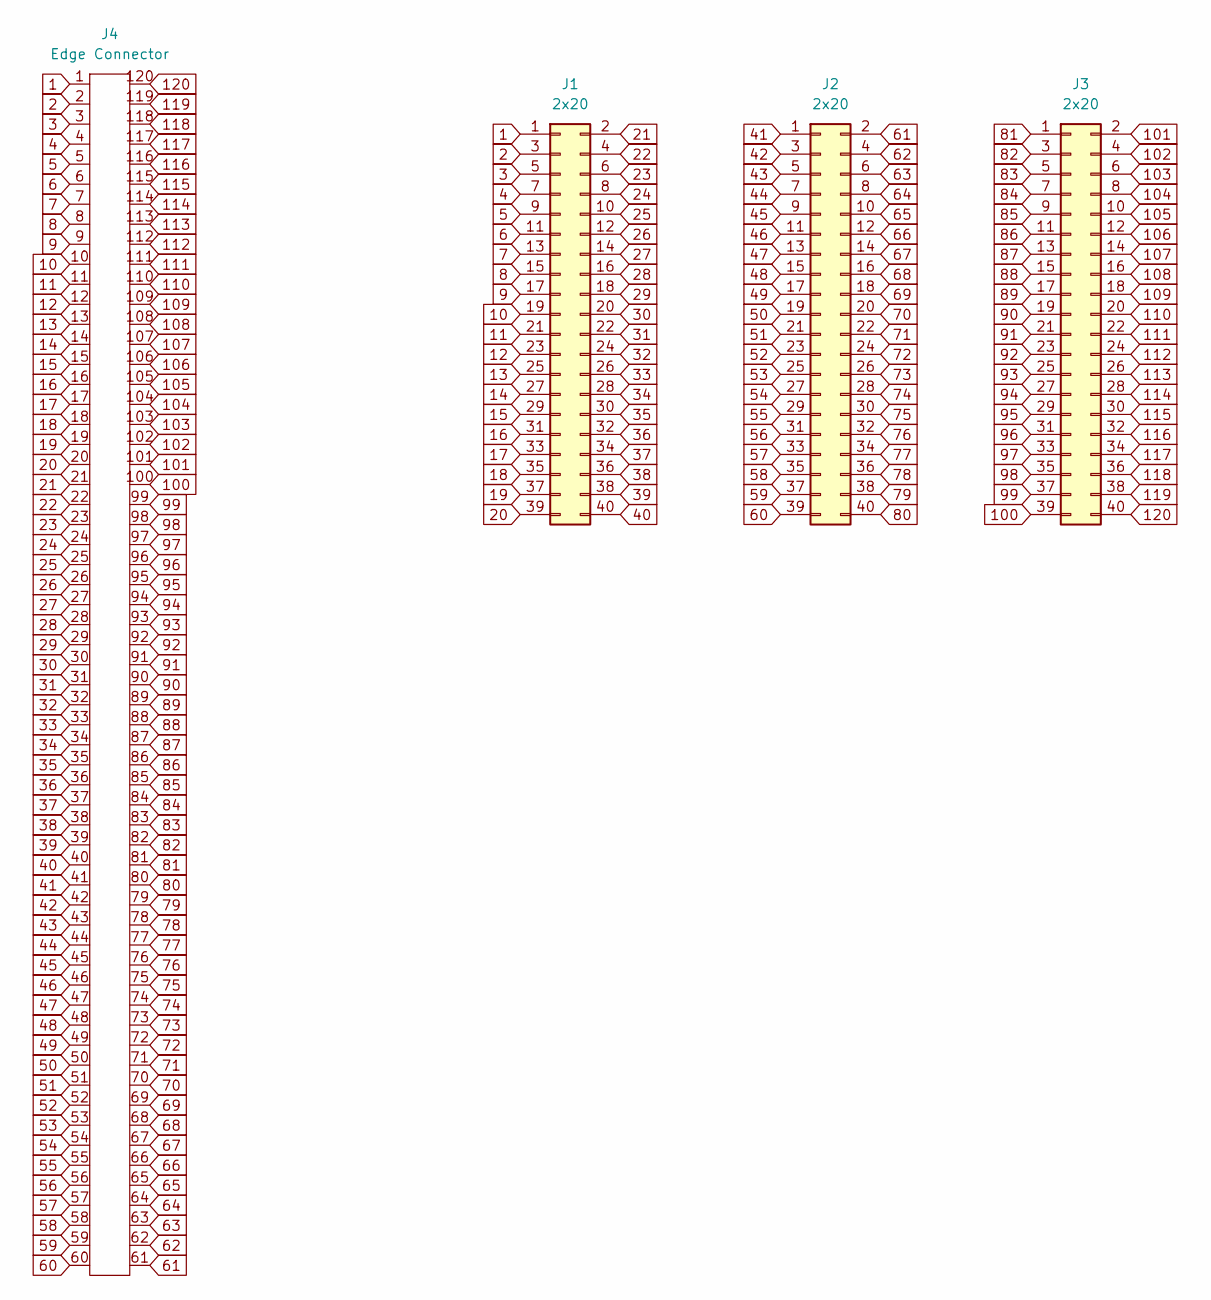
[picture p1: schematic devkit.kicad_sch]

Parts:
J1, J2, J3: 2x20; Samtec_HLE-120-02-xx-DV-TE_2x20_P2.54mm_Horizontal
J4: Edge Connector; NeoGeo_Cart_Edge_Connector

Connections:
1: J1.1, J4.1
2: J1.3, J4.2
3: J1.5, J4.3
4: J1.7, J4.4
5: J1.9, J4.5
6: J1.11, J4.6
7: J1.13, J4.7
8: J1.15, J4.8
9: J1.17, J4.9
10: J1.19, J4.10
11: J1.21, J4.11
12: J1.23, J4.12
13: J1.25, J4.13
14: J1.27, J4.14
15: J1.29, J4.15
16: J1.31, J4.16
17: J1.33, J4.17
18: J1.35, J4.18
19: J1.37, J4.19
20: J1.39, J4.20
21: J1.2, J4.21
22: J1.4, J4.22
23: J1.6, J4.23
24: J1.8, J4.24
25: J1.10, J4.25
26: J1.12, J4.26
27: J1.14, J4.27
28: J1.16, J4.28
29: J1.18, J4.29
30: J1.20, J4.30
31: J1.22, J4.31
32: J1.24, J4.32
33: J1.26, J4.33
34: J1.28, J4.34
35: J1.30, J4.35
36: J1.32, J4.36
37: J1.34, J4.37
38: J1.36, J4.38
39: J1.38, J4.39
40: J1.40, J4.40
41: J2.1, J4.41
42: J2.3, J4.42
43: J2.5, J4.43
44: J2.7, J4.44
45: J2.9, J4.45
46: J2.11, J4.46
47: J2.13, J4.47
48: J2.15, J4.48
49: J2.17, J4.49
50: J2.19, J4.50
51: J2.21, J4.51
52: J2.23, J4.52
53: J2.25, J4.53
54: J2.27, J4.54
55: J2.29, J4.55
56: J2.31, J4.56
57: J2.33, J4.57
58: J2.35, J4.58
59: J2.37, J4.59
60: J2.39, J4.60
61: J2.2, J4.61
62: J2.4, J4.62
63: J2.6, J4.63
64: J2.8, J4.64
65: J2.10, J4.65
66: J2.12, J4.66
67: J2.14, J4.67
68: J2.16, J4.68
69: J2.18, J4.69
70: J2.20, J4.70
71: J2.22, J4.71
72: J2.24, J4.72
73: J2.26, J4.73
74: J2.28, J4.74
75: J2.30, J4.75
76: J2.32, J4.76
77: J2.34, J4.77
78: J2.36, J4.78
79: J2.38, J4.79
80: J2.40, J4.80
81: J3.1, J4.81
82: J3.3, J4.82
83: J3.5, J4.83
84: J3.7, J4.84
85: J3.9, J4.85
86: J3.11, J4.86
87: J3.13, J4.87
88: J3.15, J4.88
89: J3.17, J4.89
90: J3.19, J4.90
91: J3.21, J4.91
92: J3.23, J4.92
93: J3.25, J4.93
94: J3.27, J4.94
95: J3.29, J4.95
96: J3.31, J4.96
97: J3.33, J4.97
98: J3.35, J4.98
99: J3.37, J4.99
100: J3.39, J4.100
101: J3.2, J4.101
102: J3.4, J4.102
103: J3.6, J4.103
104: J3.8, J4.104
105: J3.10, J4.105
106: J3.12, J4.106
107: J3.14, J4.107
108: J3.16, J4.108
109: J3.18, J4.109
110: J3.20, J4.110
111: J3.22, J4.111
112: J3.24, J4.112
113: J3.26, J4.113
114: J3.28, J4.114
115: J3.30, J4.115
116: J3.32, J4.116
117: J3.34, J4.117
118: J3.36, J4.118
119: J3.38, J4.119
120: J3.40, J4.120

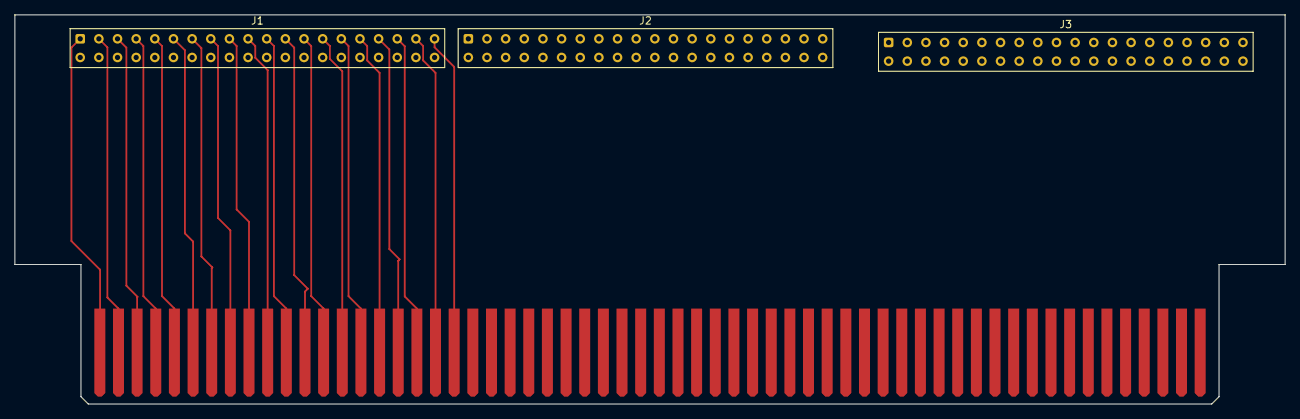
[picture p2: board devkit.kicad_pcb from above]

Board: 2 copper layers, 173.0 x 53.0 mm, 4 parts (0 on the bottom side), 120 nets.

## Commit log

2025-12-14 Include Pico role in the docs
2025-12-24 Fix ribbon cable claim and clarify C-ROM timing
    - Removed incorrect claim that boards are "connected via internal ribbon
    cables" - the CHA and PROG boards each have their own edge connector
    and plug into separate slots (CTRG1/CTRG2) on the motherboard
    - Clarified C-ROM timing: actual window is ~8 mclk (~333ns) per read,
    not 7 mclk as previously stated. The <250ns ROM requirement provides
    adequate margin within this window
    - Updated PCK1B timing description with address setup vs data valid phases
2025-12-30 Update docs and hardware project
    [devkit.kicad_pcb, devkit.kicad_sch, neopico-cart.kicad_pcb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]
2025-12-30 Mem BOM
